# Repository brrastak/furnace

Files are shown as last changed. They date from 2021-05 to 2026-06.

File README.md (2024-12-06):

# Furnace for glass fusing

Glass fusing - joining of the pieces of glass. Glass isn't really melted, but is softer than in the normal condition. Planned furnace maximum temperature - 900 °C. Unfortunetely, the project was cancelled due to political reasons. I just want to close my gestalt and finish at least PCBs and firmware.

TODO: more detailed description.

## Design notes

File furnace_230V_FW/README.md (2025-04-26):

# Furnace 230V Board Firmware

## Description

[The board](../furnace_230V_HW/README.md) is equipped with an STM8S001J3 microcontroller. Its purpose is to measure the mains voltage connected to a load, the load current, and the temperature of the triac.  
The program is simple, but - in my opinion - quite elegant. It utilizes a [simple HAL](https://github.com/brrastak/stm8s-hal.git) that I created specifically for this project, implements a single-pole digital filter for the measured analog signals, and sends the data to a controller board.

## Build Workflow

Unfortunately, STM8 is not supported by LLVM and consequently not by Rust.  
But using Rust is just so much fun! So I use a fancy workflow to compile my Rust program:

1. Compile the Rust code to the `wasm32-unknown-unknown` target.
2. Translate the Wasm code into C code using the `wasm2c` tool from the awesome [WABT project](https://github.com/WebAssembly/wabt).
3. Clean up the generated C code using a Python script, since Wasm uses a specific memory model and a byte order incompatible with the STM8 architecture. (Note: there is still an unresolved issue with handling read-only static memory, such as lookup tables.)
4. Compile and flash the final C code to the device.

## Tools Installation

- Install `wabt` (for `wasm2c`):

```bash
sudo apt install wabt
```

- [Download](https://sourceforge.net/projects/sdcc/files/snapshot_builds/) and install SDCC:

```bash
sudo apt install bison flex texinfo libboost-all-dev
./configure
make
sudo make install
```

- [Clone](https://github.com/vdudouyt/stm8flash) and install `stm8flash`:

```bash
sudo apt install pkg-config libusb-1.0-0-dev
make
sudo make install
```

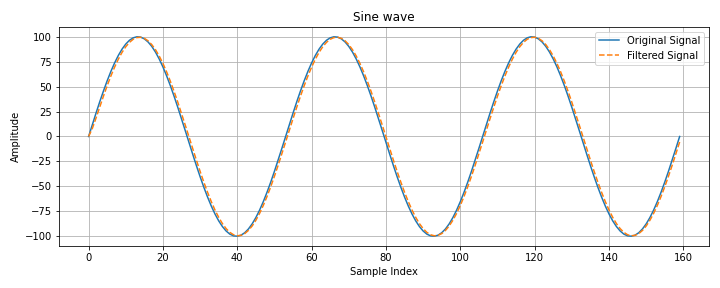
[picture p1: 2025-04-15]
simulations/digital_filter_simulation/plots/Sine wave.png

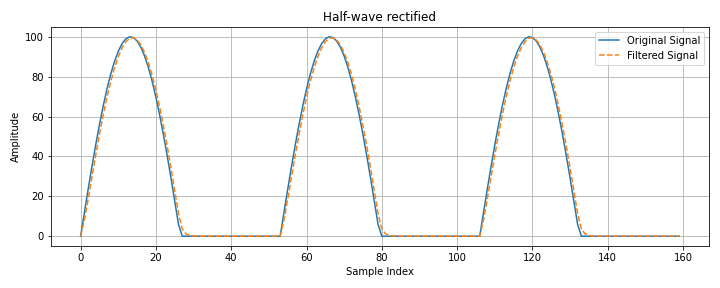
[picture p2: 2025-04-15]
simulations/digital_filter_simulation/plots/Half-wave rectified.png

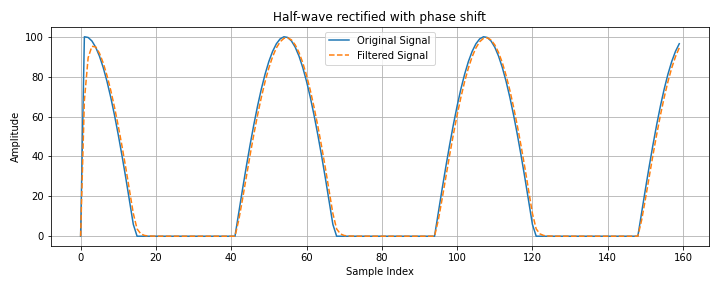
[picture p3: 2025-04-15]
simulations/digital_filter_simulation/plots/Half-wave rectified with phase shift.png

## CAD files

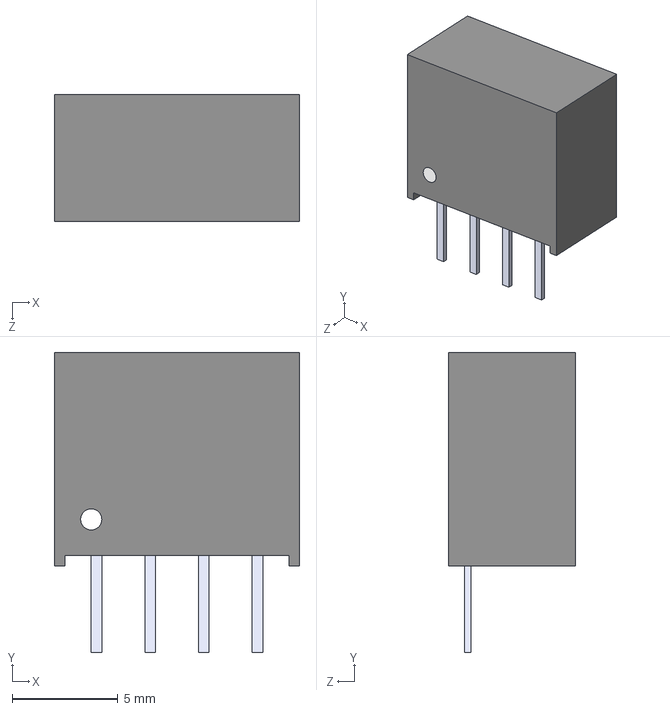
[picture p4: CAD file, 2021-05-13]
furnace_controller_HW/B0505S-1WR2.step
11.6 x 14.2 x 6.00 mm

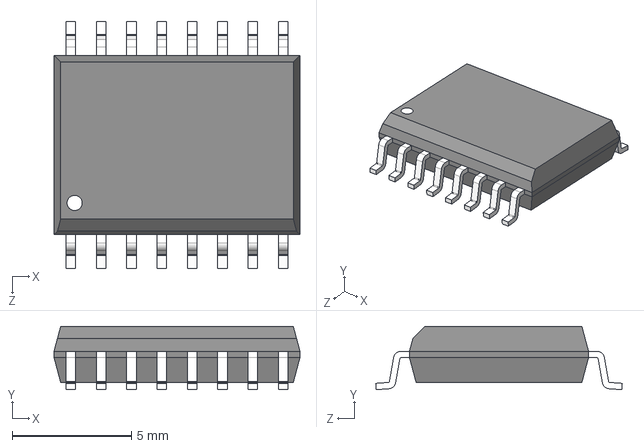
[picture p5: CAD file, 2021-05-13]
furnace_controller_HW/ADUM1301ARWZ-RL.step
10.3 x 2.65 x 10.3 mm

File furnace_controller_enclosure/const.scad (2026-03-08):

/*
    Module containing constants
*/

// OLED display recess
disp_width = 39;
disp_length = 62;
disp_x = 44;
disp_y = 22;

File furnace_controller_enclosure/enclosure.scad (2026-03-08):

//-----------------------------------------------------------------------
// Yet Another Parameterized Projectbox generator
//
//  This is a box for the furnace controller board
//
//  Version 3.3.7 (2025-04-17)
//
// This design is parameterized based on the size of a PCB.
//
// For many/complex cutoutGrills, you might need to adjust
//  the max number of elements in OpenSCAD:
//
//      Preferences->Advanced->Turn off rendering at 250000 elements
//                                                   ^^^^^^
//
//-----------------------------------------------------------------------

include <const.scad>
include <YAPPgenerator_v3.scad>


//---------------------------------------------------------
// This design is parameterized based on the size of a PCB.
//---------------------------------------------------------
// Note: length/lengte refers to X axis, 
//       width/breedte refers to Y axis,
//       height/hoogte refers to Z axis

/*
      padding-back|<------pcb length --->|<padding-front
                            RIGHT
        0    X-axis ---> 
        +----------------------------------------+   ---
        |                                        |    ^
        |                                        |   padding-right 
      Y |                                        |    v
      | |    -5,y +----------------------+       |   ---              
 B    a |         | 0,y              x,y |       |     ^              F
 A    x |         |                      |       |     |              R
 C    i |         |                      |       |     | pcb width    O
 K    s |         |                      |       |     |              N
        |         | 0,0              x,0 |       |     v              T
      ^ |    -5,0 +----------------------+       |   ---
      | |                                        |    padding-left
      0 +----------------------------------------+   ---
        0    X-as --->
                          LEFT
*/


//-- which part(s) do you want to print?
printBaseShell        = true;
printLidShell         = true;
printSwitchExtenders  = true;
printDisplayClips     = true;


myPcb = "./pcb/PCB.stl";

if (true)
{
    translate([paddingBack + wallThickness, paddingLeft + wallThickness, basePlaneThickness + standoffHeight]) 
    {
        rotate([0, 0, 90]) color("Blue") import(myPcb);
    }
}


// ********************************************************************
// The Following will be used as the first element in the pbc array

//Defined here so you can define the "Main" PCB using these if wanted
pcbLength           = 100; // front to back (X axis)
pcbWidth            = 88; // side to side (Y axis)
pcbThickness        = 1.6; 
standoffHeight      = 3.0; //-- How much the PCB needs to be raised from the base to leave room for solderings and whatnot
standoffDiameter    = 6.5;
standoffPinDiameter = 3.5;
standoffHoleSlack   = 0.2;

//===================================================================
// *** PCBs ***
// Printed Circuit Boards
//-------------------------------------------------------------------
//  Default origin =  yappCoordPCB : yappCoordBoxInside[0,0,0]
//
//  Parameters:
//   Required:
//    p(0) = name
//    p(1) = length
//    p(2) = width
//    p(3) = posx
//    p(4) = posy
//    p(5) = Thickness
//    p(6) = standoff_Height = Height to bottom of PCB from the inside of the base
//             negative measures from inside of the lid to the top of the PCB
//    p(7) = standoff_Diameter
//    p(8) = standoff_PinDiameter
//   Optional:
//    p(9) = standoff_HoleSlack (default to 0.4)

//The following can be used to get PCB values elsewhere in the script - not in pcb definition. 
//If "PCB Name" is omitted then "Main" is used
//  pcbLength           --> pcbLength("PCB Name")
//  pcbWidth            --> pcbWidth("PCB Name")
//  pcbThickness        --> pcbThickness("PCB Name") 
//  standoffHeight      --> standoffHeight("PCB Name") 
//  standoffDiameter    --> standoffDiameter("PCB Name") 
//  standoffPinDiameter --> standoffPinDiameter("PCB Name") 
//  standoffHoleSlack   --> standoffHoleSlack("PCB Name") 

pcb = 
[
  // Default Main PCB - DO NOT REMOVE the "Main" line.
  ["Main",              pcbLength,pcbWidth,    0,0,    pcbThickness,  standoffHeight, standoffDiameter, standoffPinDiameter, standoffHoleSlack]
];

//-------------------------------------------------------------------                            
//-- padding between pcb and inside wall
paddingFront        = 25;
paddingBack         = 5;
paddingRight        = 2;
paddingLeft         = 25;

//-- Edit these parameters for your own box dimensions
wallThickness       = 4;
basePlaneThickness  = 4;
lidPlaneThickness   = 4;

//-- Total height of box = lidPlaneThickness 
//                       + lidWallHeight 
//--                     + baseWallHeight 
//                       + basePlaneThickness
//-- space between pcb and lidPlane :=
//--      (bottonWallHeight+lidWallHeight) - (standoffHeight+pcbThickness)
baseWallHeight      = 14.5;
lidWallHeight       = 4.5;

//-- ridge where base and lid off box can overlap
//-- Make sure this isn't less than lidWallHeight
ridgeHeight         = 8;
ridgeSlack          = 0.2; // Gap between the inside of the lid and the outside of the base
//New in v3.3.7 
ridgeGap            = 0.1; // Gap between the bottom of the base ridge and the bottom of the lid when assembled.
roundRadius         = 2;

// Box Types are 0-4 with 0 as the default
// 0 = All edges rounded with radius (roundRadius) above
// 1 = All edges sqrtuare
// 2 = All edges chamfered by (roundRadius) above 
// 3 = Square top and bottom edges (the ones that touch the build plate) and rounded vertical edges
// 4 = Square top and bottom edges (the ones that touch the build plate) and chamfered vertical edges
// 5 = Chanfered top and bottom edges (the ones that touch the build plate) and rounded vertical edges
boxType             = 4; // Default type 0

// Set the layer height of your printer
printerLayerHeight  = 0.2;


//---------------------------
//--     C O N T R O L     --
//---------------------------
// -- Render --
renderQuality             = 8;          //-> from 1 to 32, Default = 8

// --Preview --
previewQuality            = 5;          //-> from 1 to 32, Default = 5
showSideBySide            = true;       //-> Default = true
onLidGap                  = 0;  // tip don't override to animate the lid opening
colorLid                  = "YellowGreen";   
alphaLid                  = 1;
colorBase                 = "BurlyWood";
alphaBase                 = 1;
hideLidWalls              = false;      //-> Remove the walls from the lid : only if preview and showSideBySide=true 
hideBaseWalls             = false;      //-> Remove the walls from the base : only if preview and showSideBySide=true  
showOrientation           = true;       //-> Show the Front/Back/Left/Right labels : only in preview
showPCB                   = false;      //-> Show the PCB in red : only in preview 
showSwitches              = false;      //-> Show the switches (for pushbuttons) : only in preview 
showButtonsDepressed      = false;      //-> Should the buttons in the Lid On view be in the pressed position
showOriginCoordBox        = false;      //-> Shows red bars representing the origin for yappCoordBox : only in preview 
showOriginCoordBoxInside  = false;      //-> Shows blue bars representing the origin for yappCoordBoxInside : only in preview 
showOriginCoordPCB        = false;      //-> Shows blue bars representing the origin for yappCoordBoxInside : only in preview 
showMarkersPCB            = false;      //-> Shows black bars corners of the PCB : only in preview 
showMarkersCenter         = false;      //-> Shows magenta bars along the centers of all faces  
inspectX                  = 0;          //-> 0=none (>0 from Back)
inspectY                  = 0;          //-> 0=none (>0 from Right)
inspectZ                  = 0;          //-> 0=none (>0 from Bottom)
inspectXfromBack          = true;       //-> View from the inspection cut foreward
inspectYfromLeft          = true;       //-> View from the inspection cut to the right
inspectZfromBottom        = true;       //-> View from the inspection cut up
//---------------------------
//--     C O N T R O L     --
//---------------------------

//-------------------------------------------------------------------
//-------------------------------------------------------------------
// Start of Debugging config (used if not overridden in template)
// ------------------------------------------------------------------
// ------------------------------------------------------------------
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

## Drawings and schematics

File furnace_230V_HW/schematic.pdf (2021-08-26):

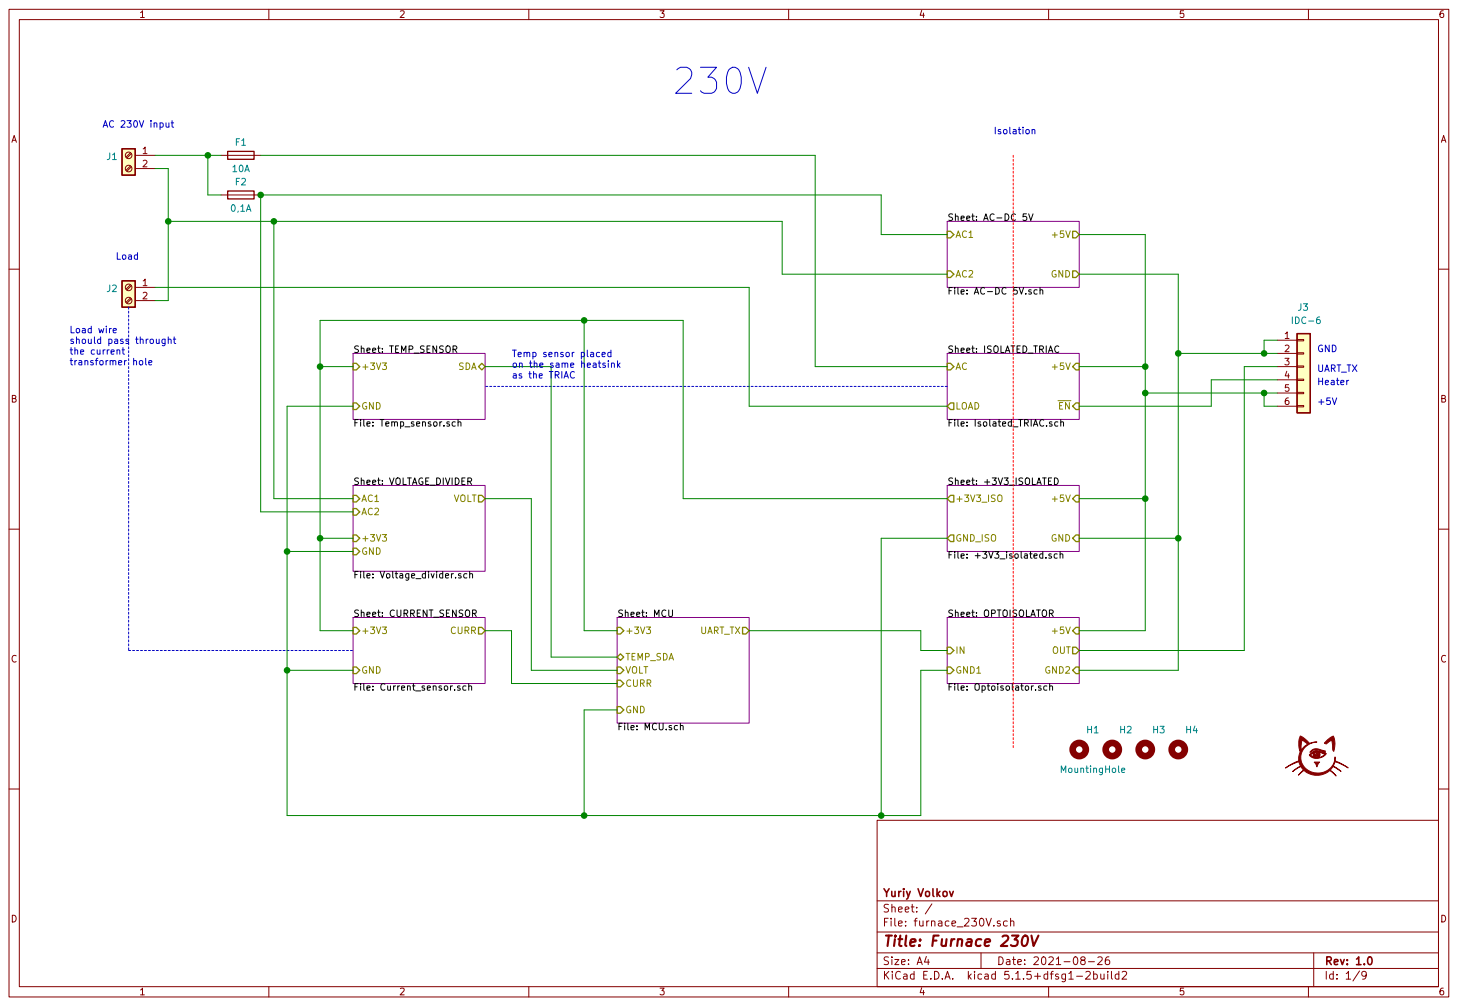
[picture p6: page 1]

Load wire should pass throught

File: furnace_230V.sch Sheet: / Yuriy Volkov

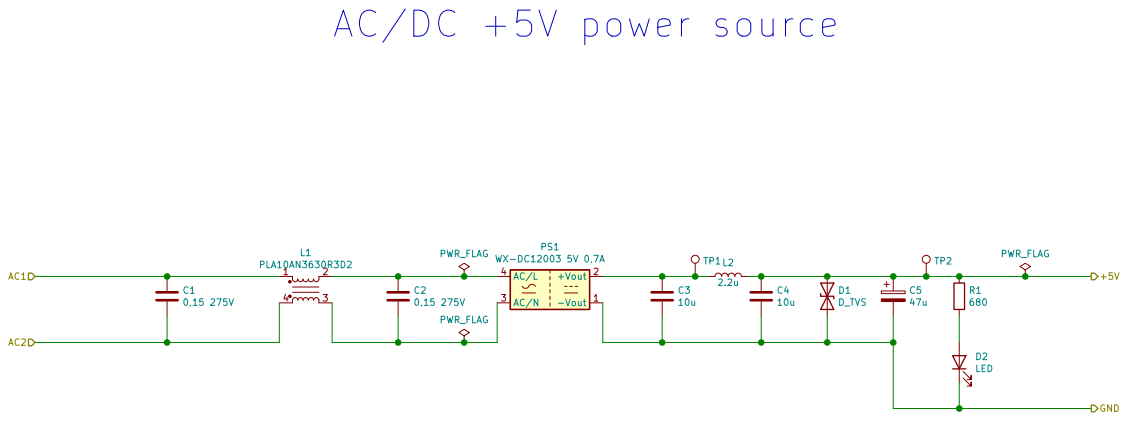
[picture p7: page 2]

File: AC-DC 5V.sch Sheet: /AC-DC 5V/ Yuriy Volkov

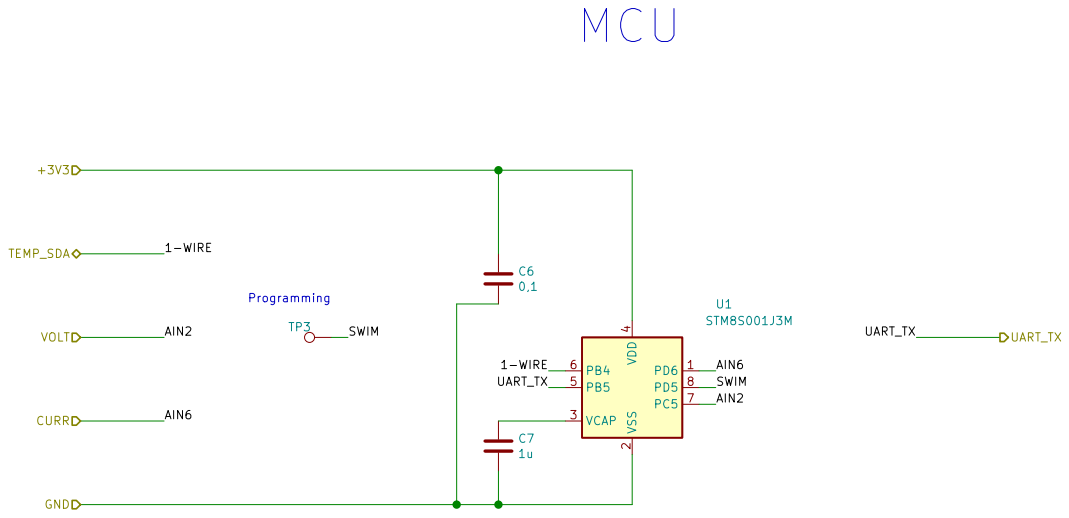
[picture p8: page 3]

File: MCU.sch Sheet: /MCU/ Yuriy Volkov C7

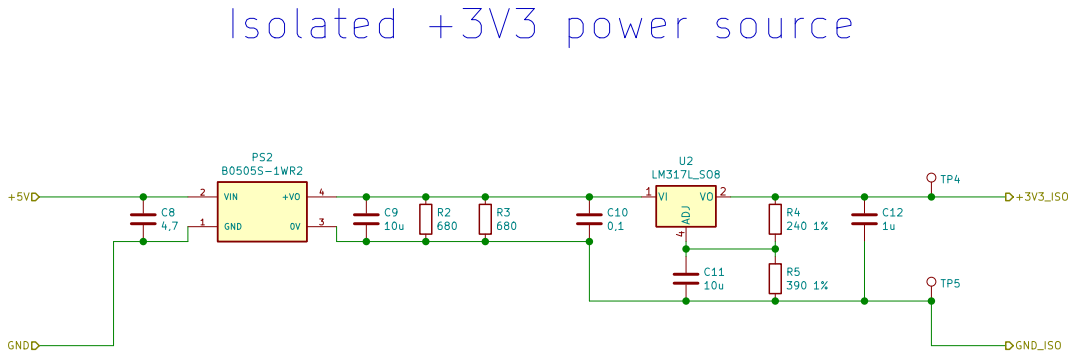
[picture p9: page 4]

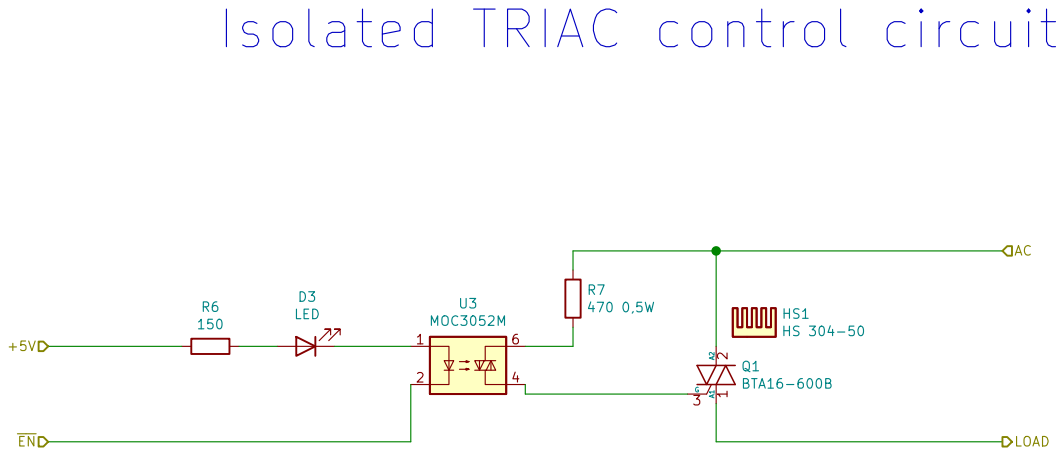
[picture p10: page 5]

AC Isolated TRIAC control circuit

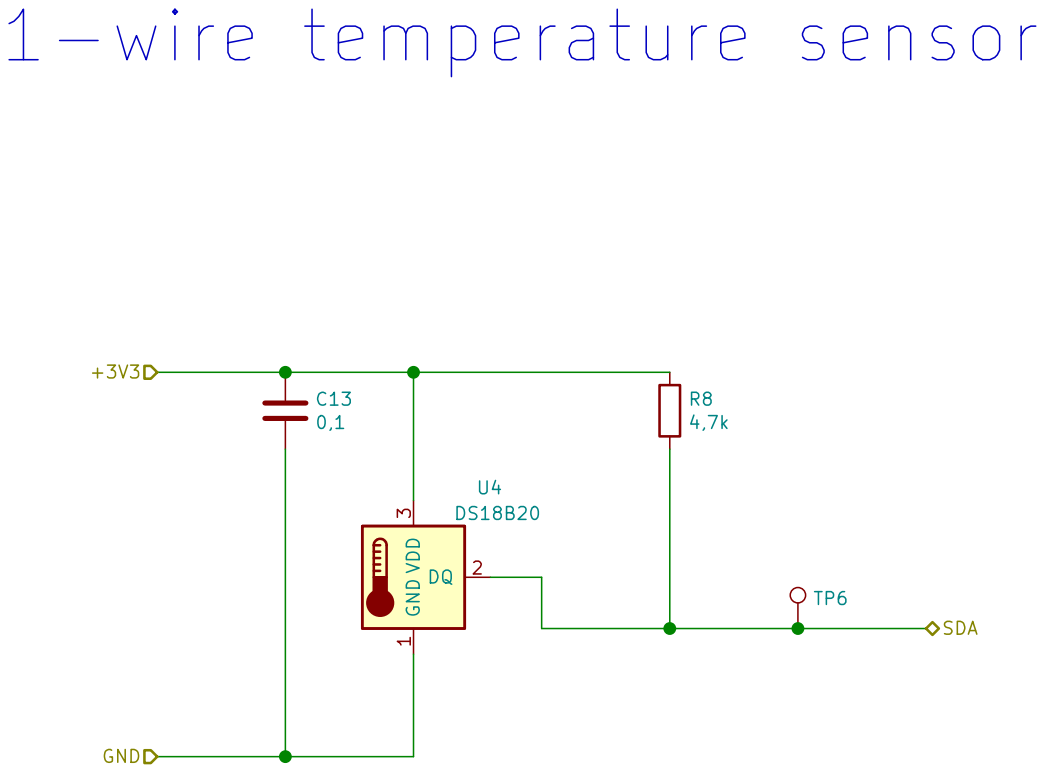
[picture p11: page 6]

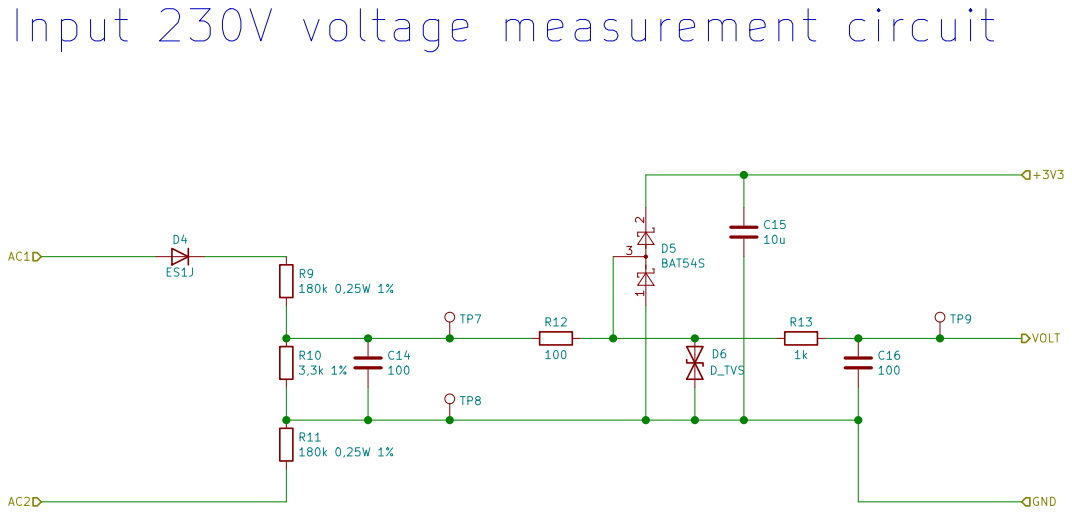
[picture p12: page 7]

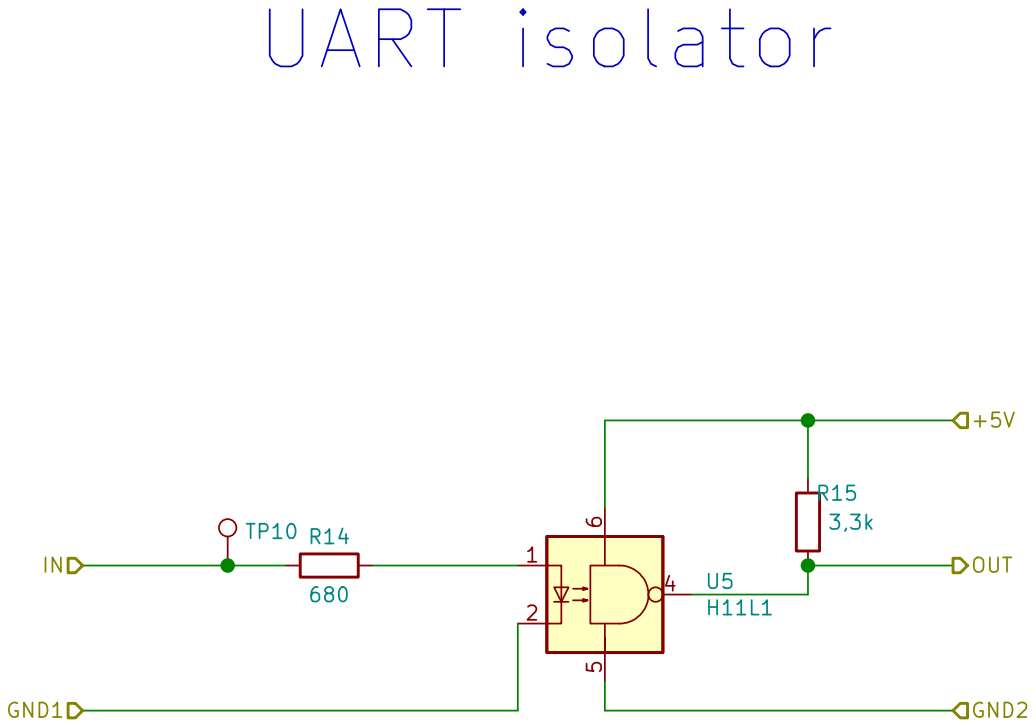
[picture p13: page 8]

File: Optoisolator.sch Sheet: /OPTOISOLATOR/ Yuriy Volkov R14

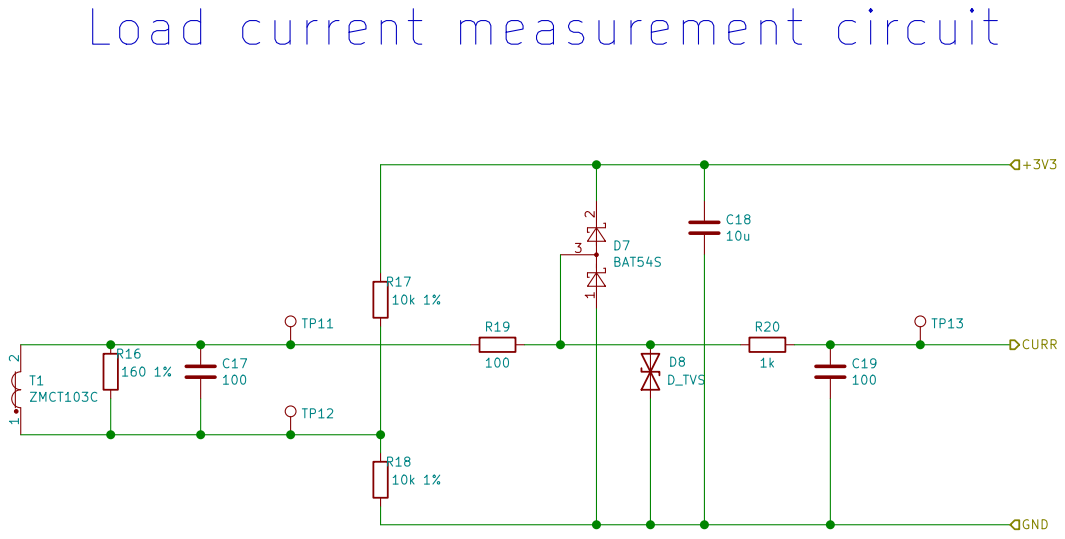
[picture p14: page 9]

+3V3 GND Load current measurement circuit

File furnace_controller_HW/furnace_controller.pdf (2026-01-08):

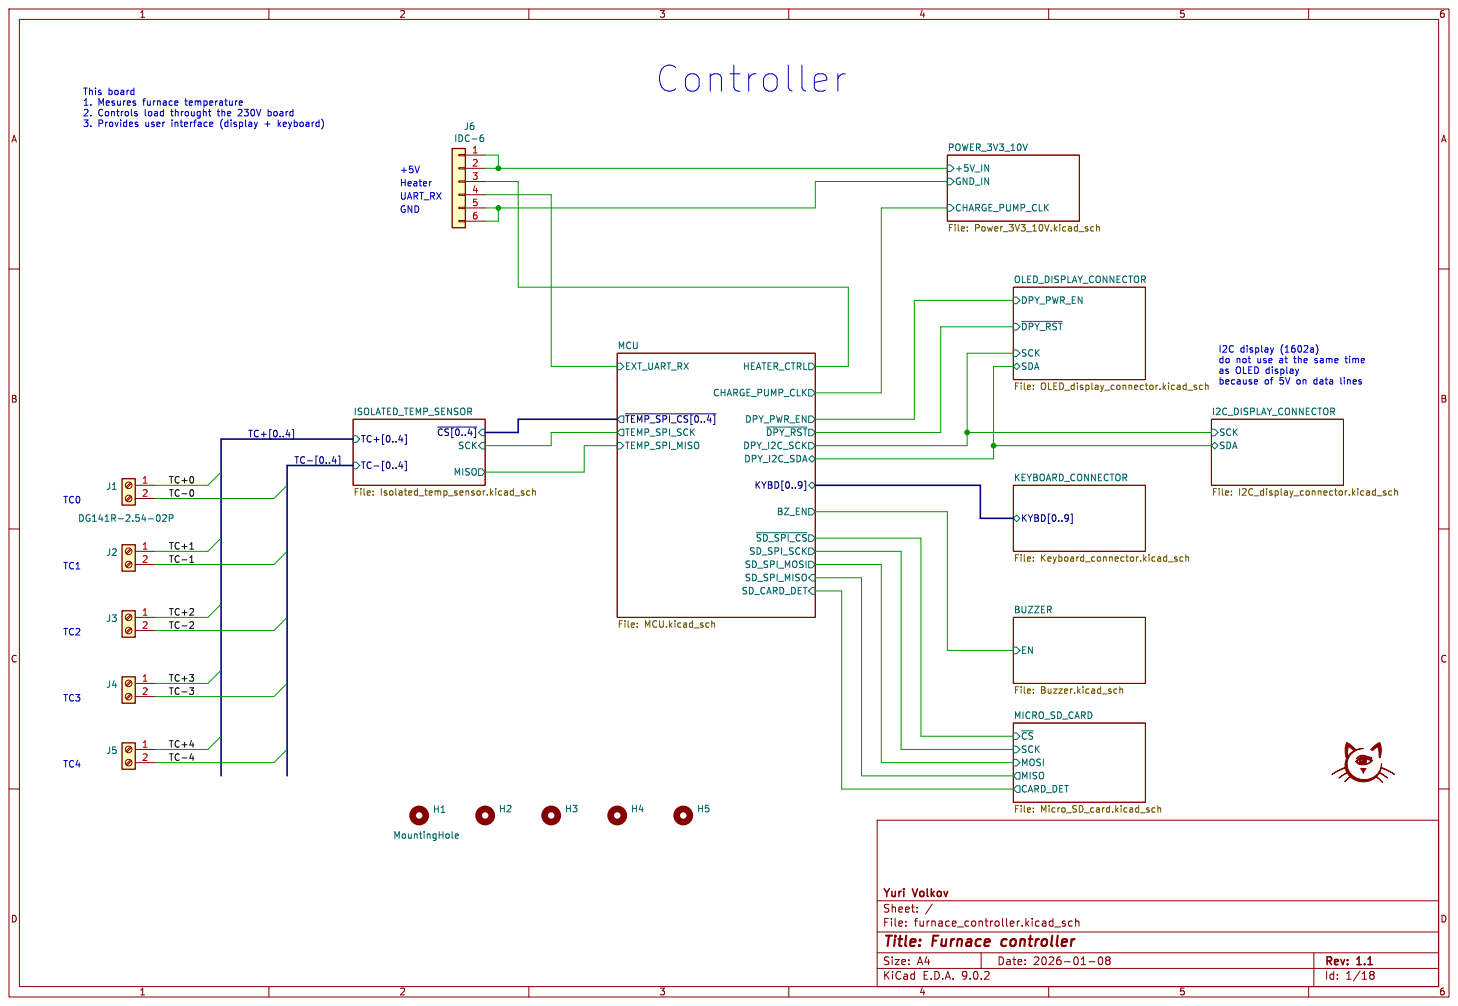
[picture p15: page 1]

as OLED display because of 5V on data lines UART_RX

I2C display (1602a) do not use at the same time

File: Buzzer.kicad_sch ~{CS} MOSI SCK MISO

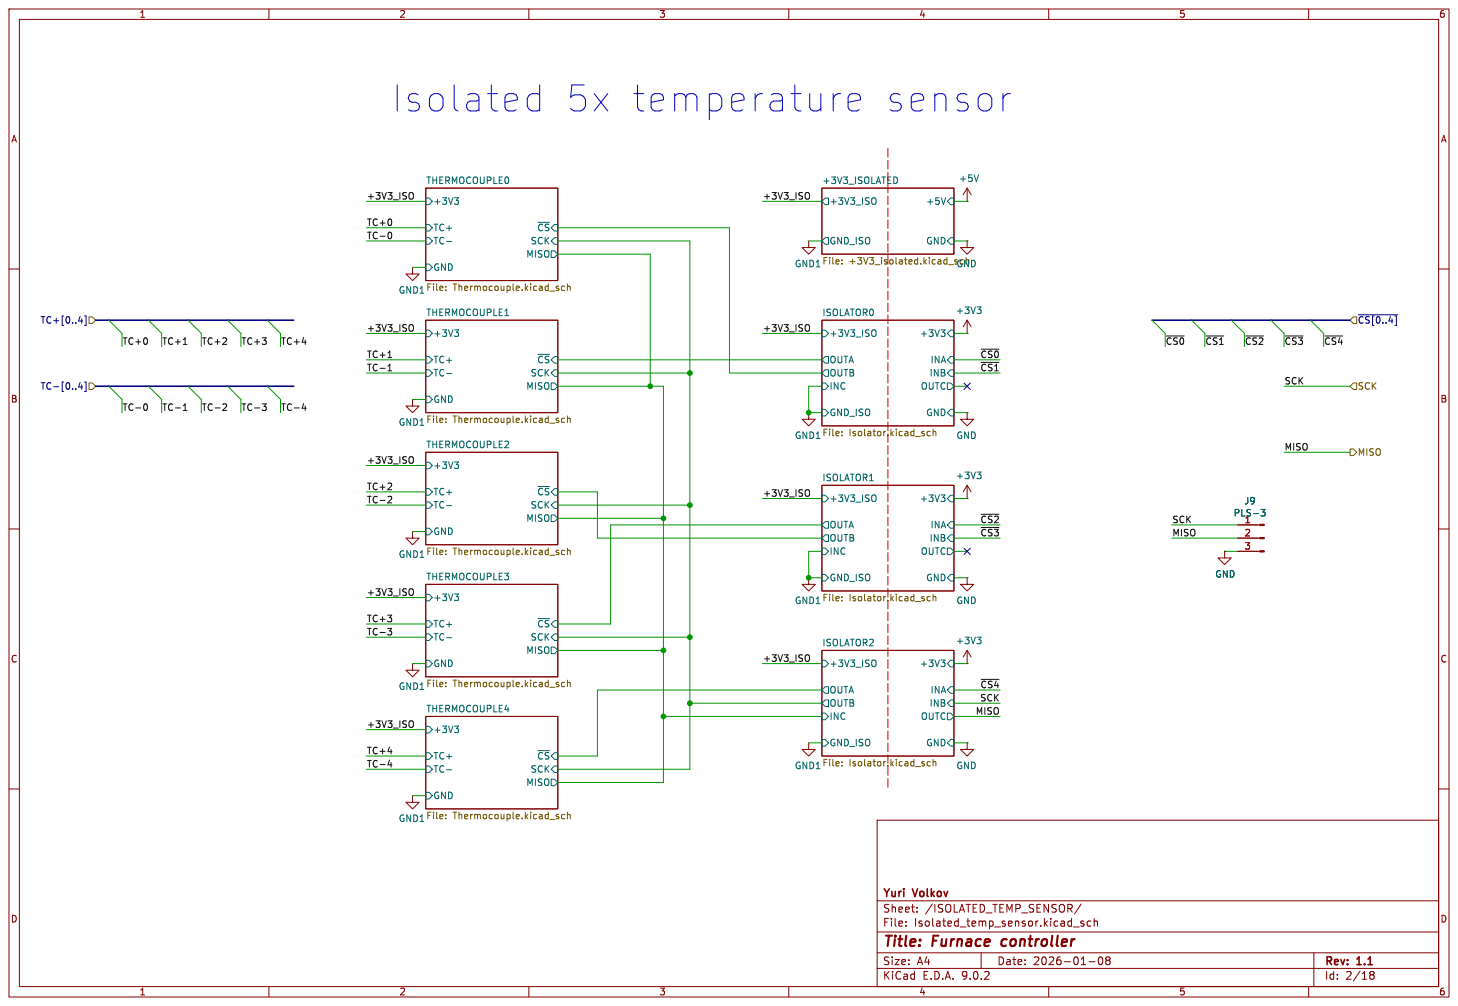
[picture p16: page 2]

Id: 2/18 Title: Furnace controller File: Isolated_temp_sensor.kicad_sch Sheet: /ISOLATED_TEMP_SENSOR/ Yuri Volkov

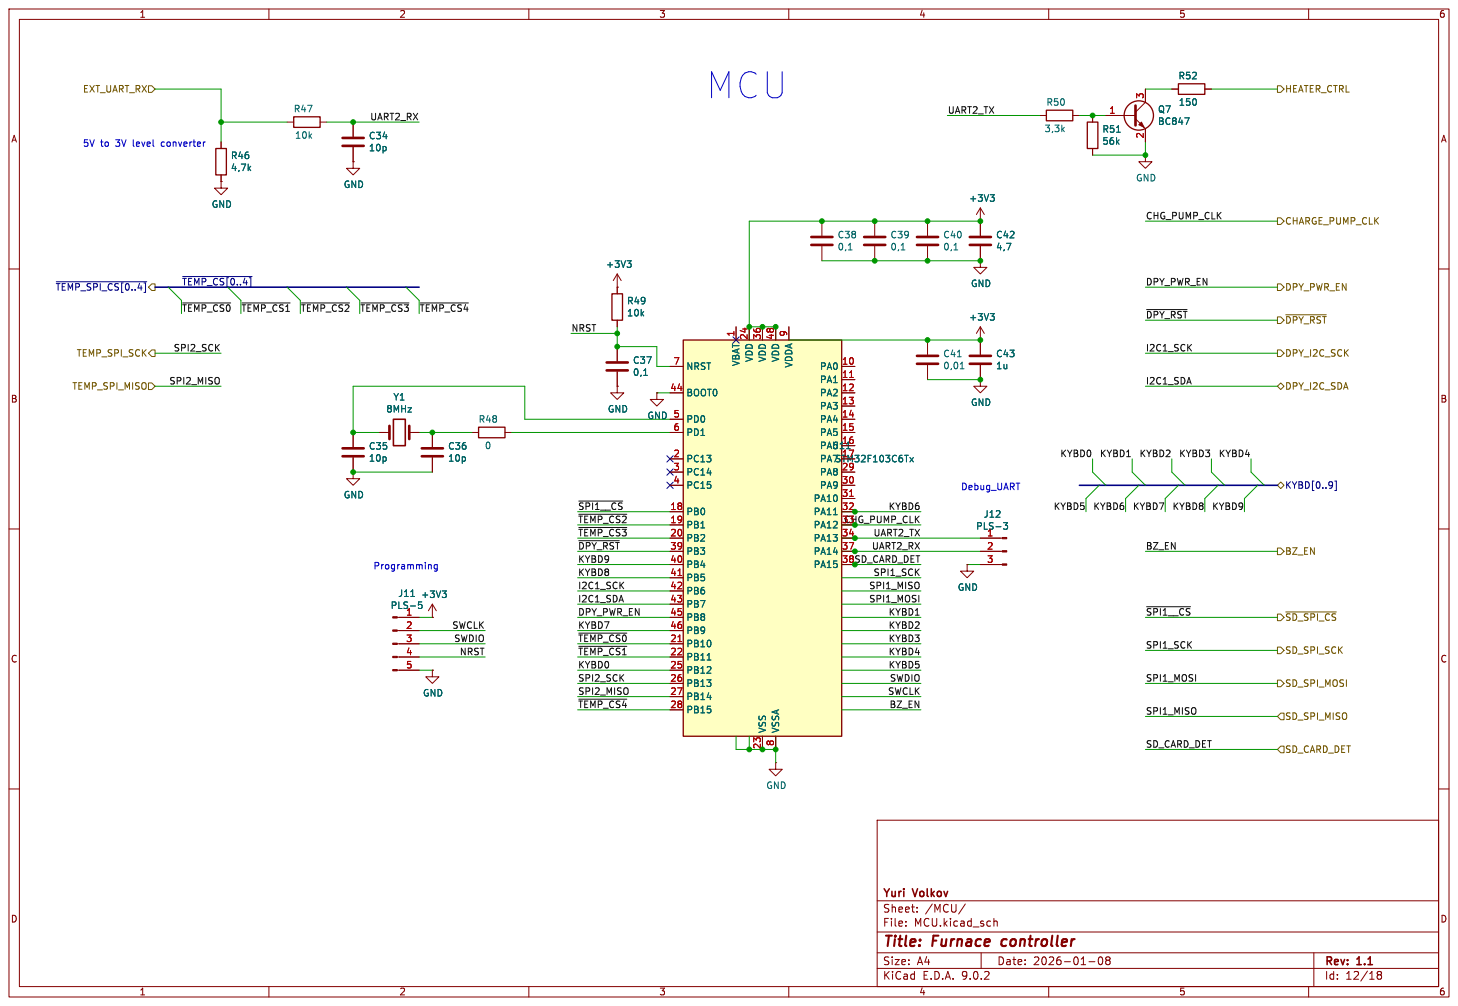
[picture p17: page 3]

1 VDD 24 VDD 36 VSS 23 VDD 48 VSSA

Id: 12/18 Title: Furnace controller File: MCU.kicad_sch Sheet: /MCU/ Yuri Volkov


Id: 13/18 Title: Furnace controller File: Power_3V3_10V.kicad_sch Sheet: /POWER_3V3_10V/ Yuri Volkov



Id: 15/18 Title: Furnace controller File: Keyboard_connector.kicad_sch Sheet: /KEYBOARD_CONNECTOR/ Yuri Volkov


Id: 16/18 Title: Furnace controller File: Buzzer.kicad_sch Sheet: /BUZZER/ Yuri Volkov


Id: 17/18 Title: Furnace controller File: Micro_SD_card.kicad_sch Sheet: /MICRO_SD_CARD/ Yuri Volkov R54


Id: 18/18 Title: Furnace controller File: I2C_display_connector.kicad_sch Sheet: /I2C_DISPLAY_CONNECTOR/ Yuri Volkov


1 SCK 5 SO 7 ~{CS}6 U2 MAX31855EASA MISO

Id: 3/18 Title: Furnace controller File: Thermocouple.kicad_sch Sheet: /ISOLATED_TEMP_SENSOR/THERMOCOUPLE0/ Yuri Volkov


1 SCK 5 SO 7 ~{CS}6 U5 MAX31855EASA MISO

Id: 4/18 Title: Furnace controller File: Thermocouple.kicad_sch Sheet: /ISOLATED_TEMP_SENSOR/THERMOCOUPLE1/ Yuri Volkov


1 SCK 5 SO 7 ~{CS}6 U6 MAX31855EASA MISO

Id: 5/18 Title: Furnace controller File: Thermocouple.kicad_sch Sheet: /ISOLATED_TEMP_SENSOR/THERMOCOUPLE2/ Yuri Volkov


1 SCK 5 SO 7 ~{CS}6 U7 MAX31855EASA MISO

Id: 6/18 Title: Furnace controller File: Thermocouple.kicad_sch Sheet: /ISOLATED_TEMP_SENSOR/THERMOCOUPLE3/ Yuri Volkov


1 SCK 5 SO 7 ~{CS}6 U8 MAX31855EASA MISO

Id: 7/18 Title: Furnace controller File: Thermocouple.kicad_sch Sheet: /ISOLATED_TEMP_SENSOR/THERMOCOUPLE4/ Yuri Volkov


Id: 8/18 Title: Furnace controller File: +3V3_isolated.kicad_sch Sheet: /ISOLATED_TEMP_SENSOR/+3V3_ISOLATED/ Yuri Volkov C20


Id: 9/18 Title: Furnace controller File: Isolator.kicad_sch Sheet: /ISOLATED_TEMP_SENSOR/ISOLATOR0/ Yuri Volkov


Id: 10/18 Title: Furnace controller File: Isolator.kicad_sch Sheet: /ISOLATED_TEMP_SENSOR/ISOLATOR1/ Yuri Volkov


Id: 11/18 Title: Furnace controller File: Isolator.kicad_sch Sheet: /ISOLATED_TEMP_SENSOR/ISOLATOR2/ Yuri Volkov

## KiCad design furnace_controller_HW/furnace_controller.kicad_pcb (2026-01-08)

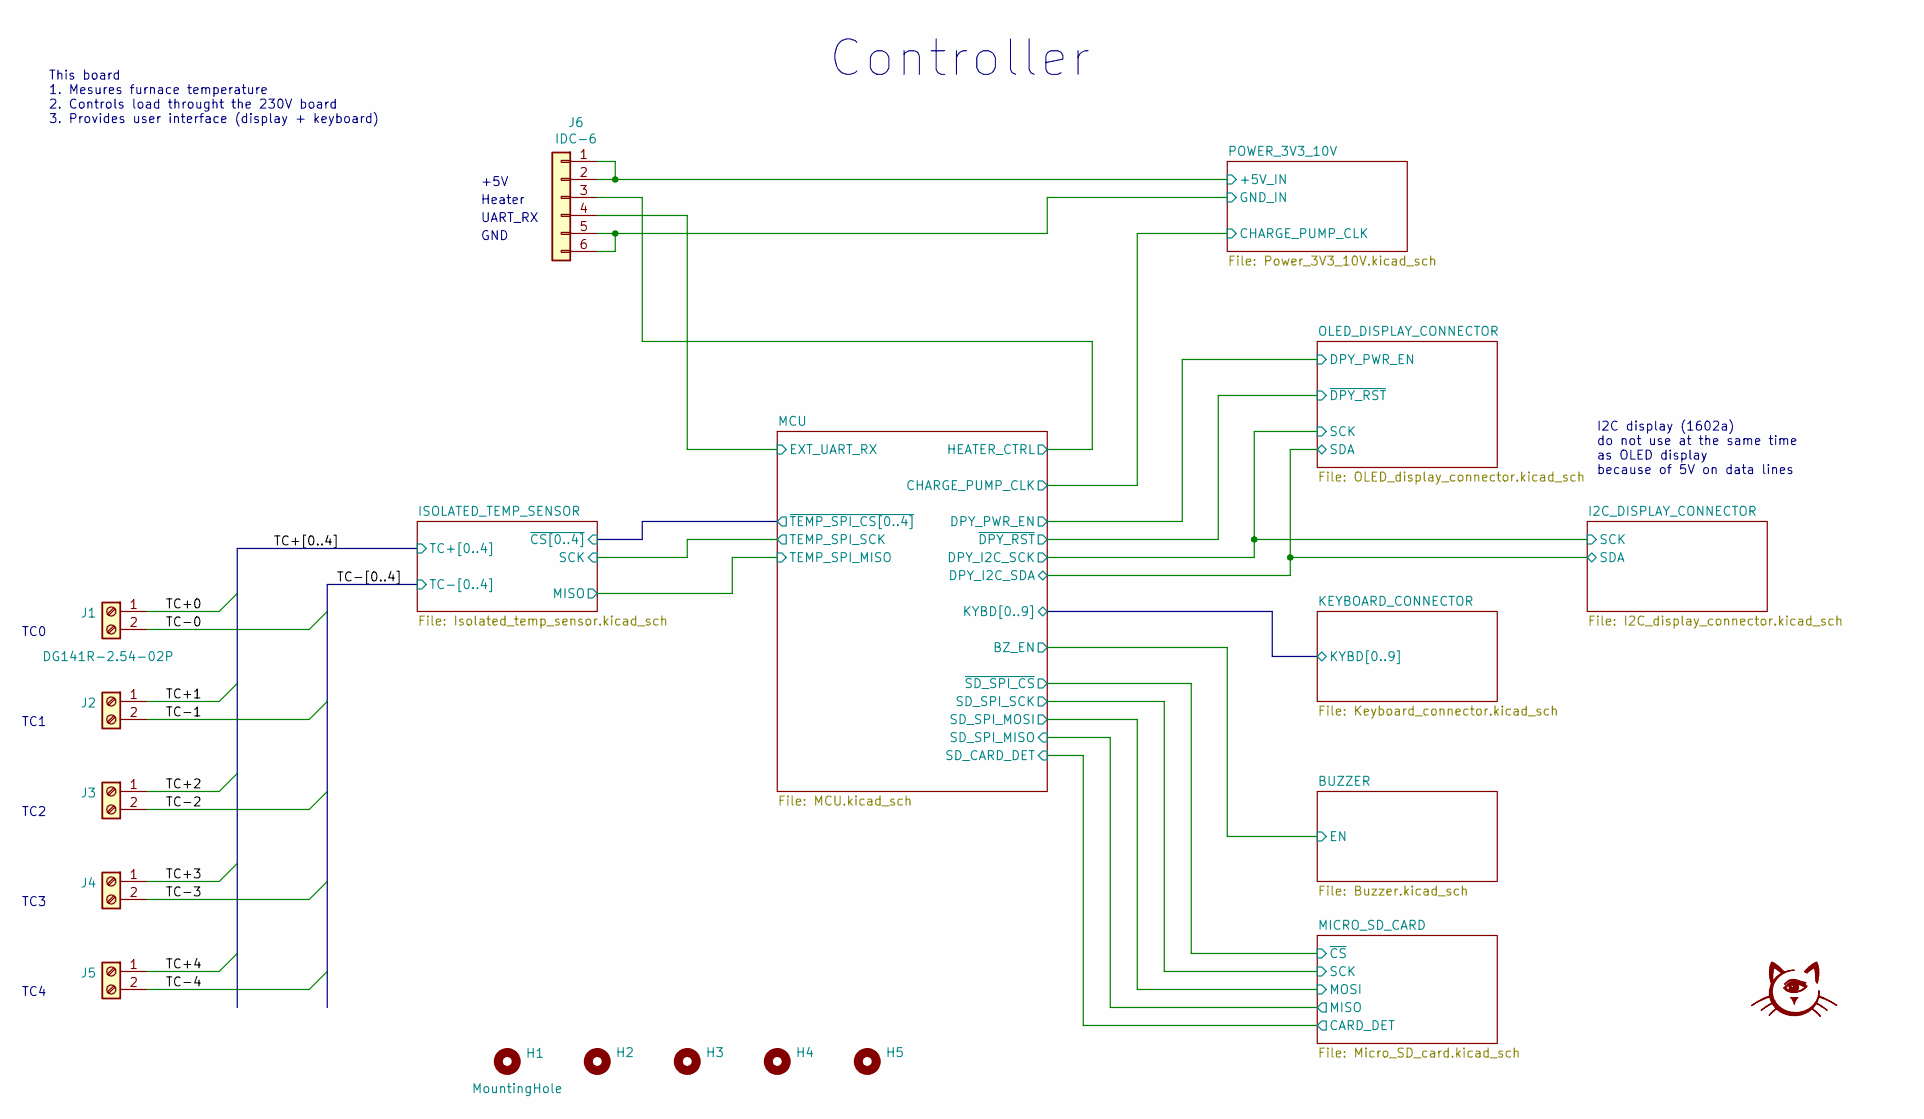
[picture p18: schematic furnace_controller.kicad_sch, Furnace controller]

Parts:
G1: LOGO; stamp
H1, H2, H3, H4, H5: MountingHole; hole_D3.5mm
J1, J2, J3, J4, J5: DG141R-2.54-02P
J6: IDC-6; IDC-Header_2x03_P2.54mm_Vertical

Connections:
/MCU/EXT_UART_RX: J6.4; also elsewhere on the board
/MCU/HEATER_CTRL: J6.3; also elsewhere on the board
/POWER_3V3_10V/+5V_IN: J6.1, J6.2; also elsewhere on the board
/TC+0: J1.1; also elsewhere on the board
/TC+1: J2.1; also elsewhere on the board
/TC+2: J3.1; also elsewhere on the board
/TC+3: J4.1; also elsewhere on the board
/TC+4: J5.1; also elsewhere on the board
/TC-0: J1.2; also elsewhere on the board
/TC-1: J2.2; also elsewhere on the board
/TC-2: J3.2; also elsewhere on the board
/TC-3: J4.2; also elsewhere on the board
/TC-4: J5.2; also elsewhere on the board
GND: J6.5, J6.6; also elsewhere on the board

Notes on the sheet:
Controller
TC0
UART_RX
GND
+5V
I2C display (1602a) do not use at the same time as OLED display because of 5V on data lines
TC2
TC1
TC4
TC3
This board 1. Mesures furnace temperature 2. Controls load throught the 230V board 3. Provides user interface (display + keyboard)
Heater

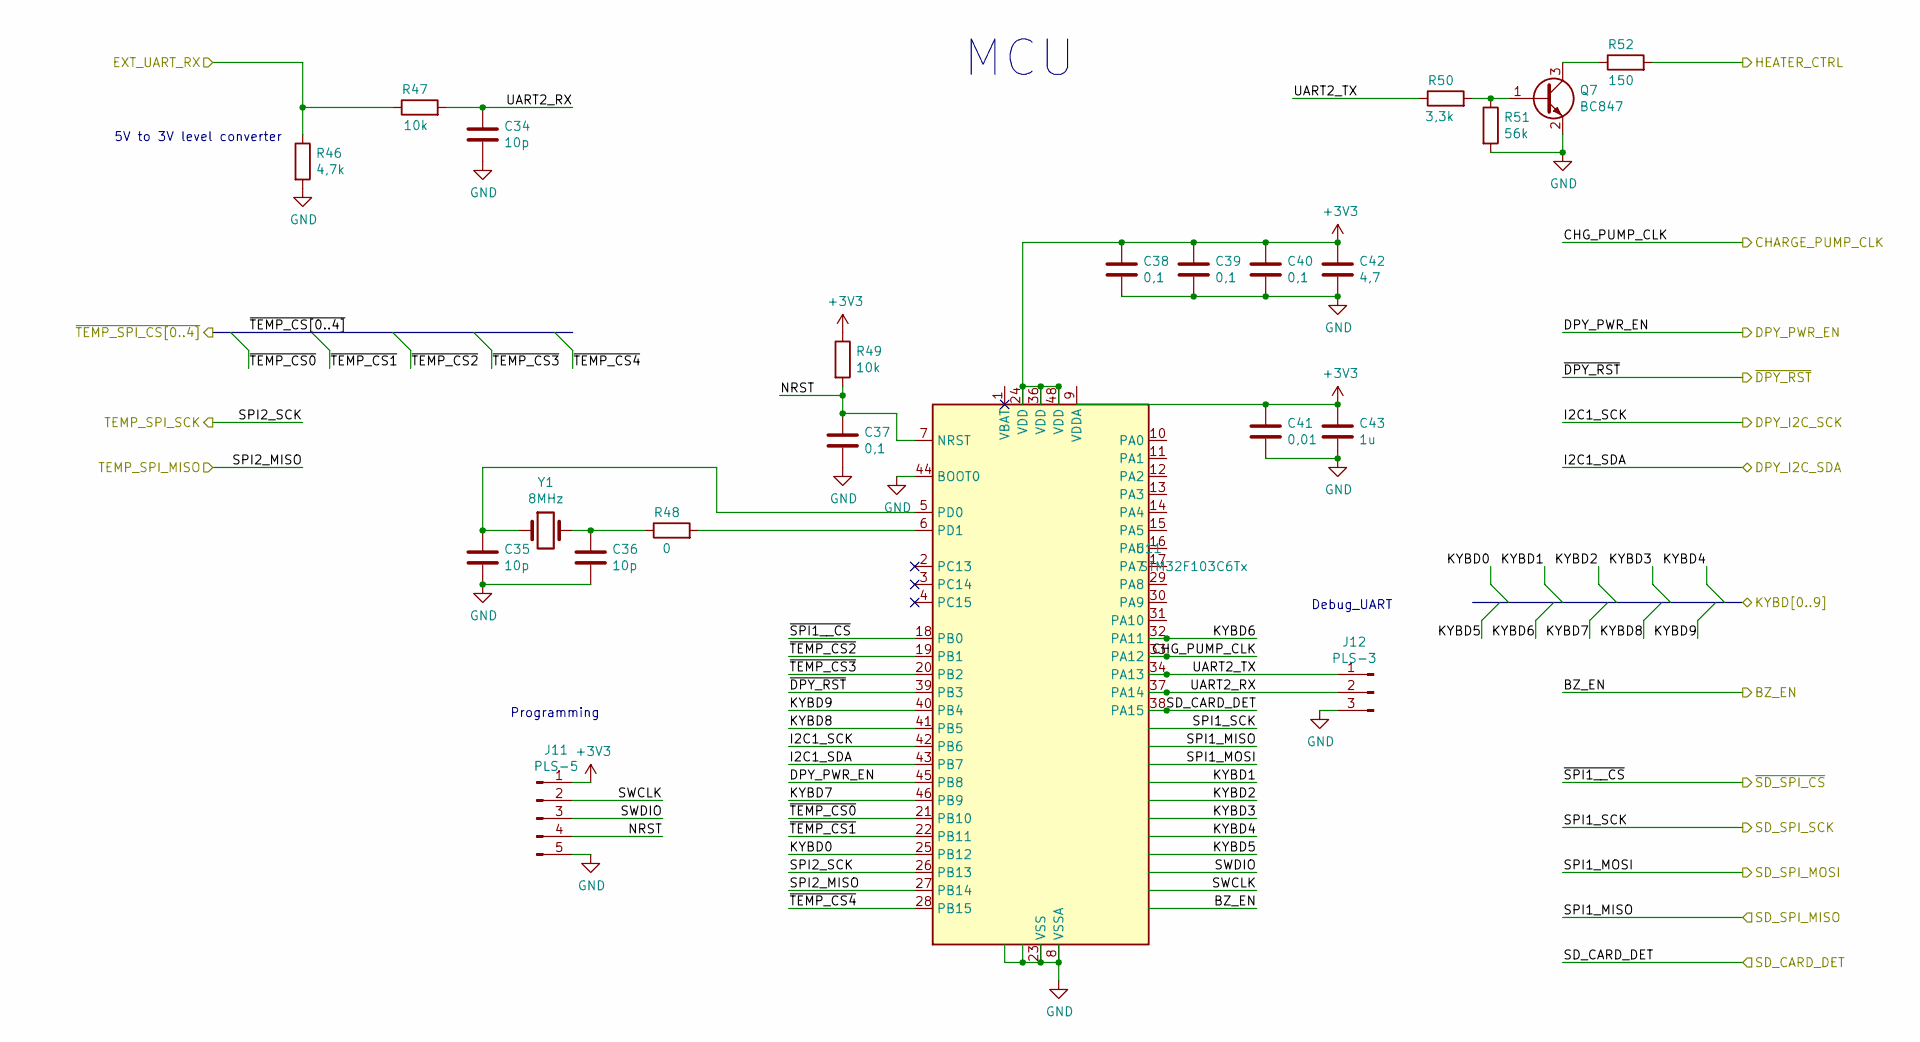
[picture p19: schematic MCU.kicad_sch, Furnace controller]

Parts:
C34, C35, C36: 10p; C_0603_1608Metric_Pad1.08x0.95mm_HandSolder
C37, C38, C39, C40: 0,1; C_0603_1608Metric_Pad1.08x0.95mm_HandSolder
C41: 0,01; C_0603_1608Metric_Pad1.08x0.95mm_HandSolder
C42: 4,7; C_1206_3216Metric_Pad1.33x1.80mm_HandSolder
C43: 1u; C_0603_1608Metric_Pad1.08x0.95mm_HandSolder
J11: PLS-5; PinHeader_1x05_P2.54mm_Vertical
J12: PLS-3; PinHeader_1x03_P2.54mm_Vertical
Q7: BC847; SOT-23
R46: 4,7k; R_0603_1608Metric_Pad0.98x0.95mm_HandSolder
R47, R49: 10k; R_0603_1608Metric_Pad0.98x0.95mm_HandSolder
R48: 0; R_0603_1608Metric_Pad0.98x0.95mm_HandSolder
R50: 3,3k; R_0603_1608Metric_Pad0.98x0.95mm_HandSolder
R51: 56k; R_0603_1608Metric_Pad0.98x0.95mm_HandSolder
R52: 150; R_0603_1608Metric_Pad0.98x0.95mm_HandSolder
U11: STM32F103C6Tx; LQFP-48_7x7mm_P0.5mm
Y1: 8MHz; Crystal_SMD_HC49-SD

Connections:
+3V3: C38.1, C39.1, C40.1, C41.1, C42.1, C43.1, J11.1, R49.1, U11.9 (VDDA), U11.24 (VDD), U11.36 (VDD), U11.48 (VDD); also elsewhere on the board
/ISOLATED_TEMP_SENSOR/MISO: U11.27 (PB14); also elsewhere on the board
/ISOLATED_TEMP_SENSOR/SCK: U11.26 (PB13); also elsewhere on the board
/ISOLATED_TEMP_SENSOR/~CS0: U11.21 (PB10); also elsewhere on the board
/ISOLATED_TEMP_SENSOR/~CS1: U11.22 (PB11); also elsewhere on the board
/ISOLATED_TEMP_SENSOR/~CS2: U11.19 (PB1); also elsewhere on the board
/ISOLATED_TEMP_SENSOR/~CS3: U11.20 (PB2); also elsewhere on the board
/ISOLATED_TEMP_SENSOR/~CS4: U11.28 (PB15); also elsewhere on the board
/KEYBOARD_CONNECTOR/KYBD0: U11.25 (PB12); also elsewhere on the board
/KEYBOARD_CONNECTOR/KYBD1: U11.29 (PA8); also elsewhere on the board
/KEYBOARD_CONNECTOR/KYBD2: U11.30 (PA9); also elsewhere on the board
/KEYBOARD_CONNECTOR/KYBD3: U11.31 (PA10); also elsewhere on the board
/KEYBOARD_CONNECTOR/KYBD4: U11.32 (PA11); also elsewhere on the board
/KEYBOARD_CONNECTOR/KYBD5: U11.33 (PA12); also elsewhere on the board
/KEYBOARD_CONNECTOR/KYBD6: U11.10 (PA0); also elsewhere on the board
/KEYBOARD_CONNECTOR/KYBD7: U11.46 (PB9); also elsewhere on the board
/KEYBOARD_CONNECTOR/KYBD8: U11.41 (PB5); also elsewhere on the board
/KEYBOARD_CONNECTOR/KYBD9: U11.40 (PB4); also elsewhere on the board
/MCU/BZ_EN: U11.38 (PA15); also elsewhere on the board
/MCU/CHARGE_PUMP_CLK: U11.11 (PA1); also elsewhere on the board
/MCU/DPY_I2C_SCK: U11.42 (PB6); also elsewhere on the board
/MCU/DPY_I2C_SDA: U11.43 (PB7); also elsewhere on the board
/MCU/DPY_PWR_EN: U11.45 (PB8); also elsewhere on the board
/MCU/EXT_UART_RX: R46.1, R47.1; also elsewhere on the board
/MCU/HEATER_CTRL: R52.2; also elsewhere on the board
/MCU/NRST: C37.1, J11.4, R49.2, U11.7 (NRST)
/MCU/~DPY_RST: U11.39 (PB3); also elsewhere on the board
/MICRO_SD_CARD/CARD_DET: U11.14 (PA4); also elsewhere on the board
/MICRO_SD_CARD/MISO: U11.16 (PA6); also elsewhere on the board
/MICRO_SD_CARD/MOSI: U11.17 (PA7); also elsewhere on the board
/MICRO_SD_CARD/SCK: U11.15 (PA5); also elsewhere on the board
/MICRO_SD_CARD/~CS: U11.18 (PB0); also elsewhere on the board
GND: C34.2, C35.2, C36.2, C37.2, C38.2, C39.2, C40.2, C41.2, C42.2, C43.2, J11.5, J12.3, Q7.2 (E), R46.2, R51.2, U11.8 (VSSA), U11.23 (VSS), U11.35 (VSS), U11.44 (BOOT0), U11.47 (VSS); also elsewhere on the board
unnamed: C35.1, U11.5 (PD0), Y1.1
unnamed: C36.1, R48.1, Y1.2
unnamed: Q7.1 (B), R50.2, R51.1
unnamed: Q7.3 (C), R52.1
unnamed: R48.2, U11.6 (PD1)

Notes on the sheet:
Debug_UART
Programming
MCU
5V to 3V level converter

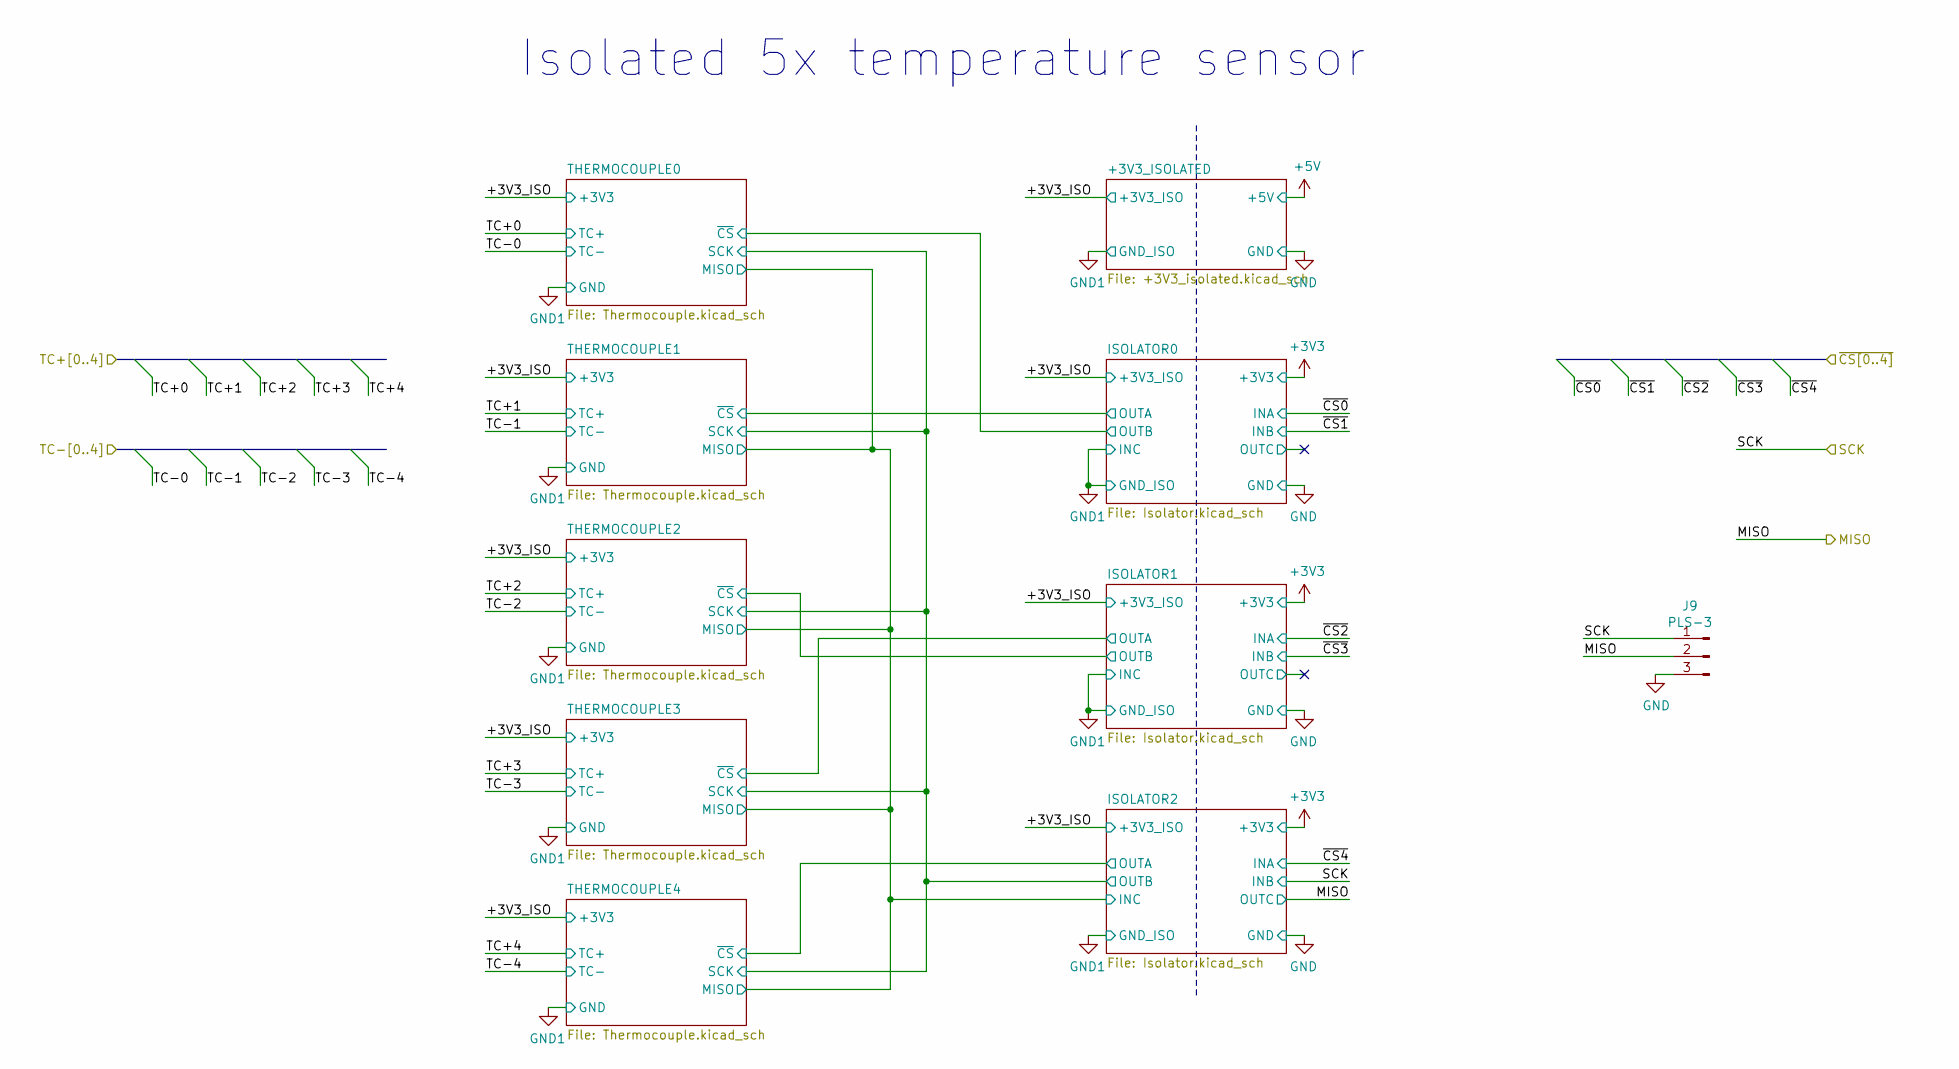
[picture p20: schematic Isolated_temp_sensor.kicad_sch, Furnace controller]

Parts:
J9: PLS-3; PinHeader_1x03_P2.54mm_Vertical

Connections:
/ISOLATED_TEMP_SENSOR/MISO: J9.2; also elsewhere on the board
/ISOLATED_TEMP_SENSOR/SCK: J9.1; also elsewhere on the board
GND: J9.3; also elsewhere on the board

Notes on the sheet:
Isolated 5x temperature sensor

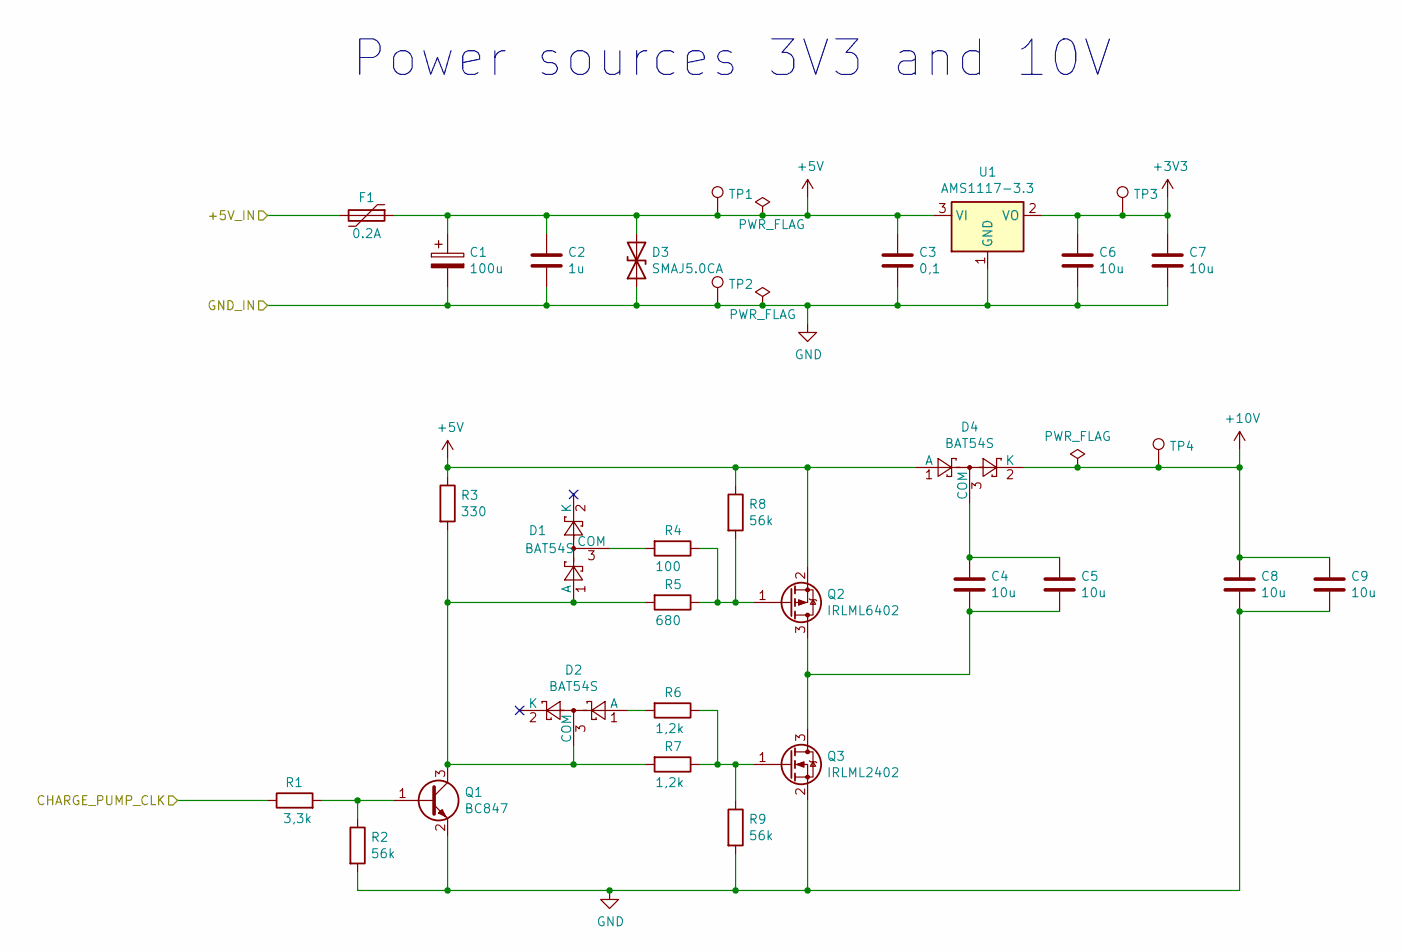
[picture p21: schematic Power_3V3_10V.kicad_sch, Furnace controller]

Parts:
C1: 100u; CP_Radial_D5.0mm_P2.00mm
C2: 1u; C_0603_1608Metric_Pad1.08x0.95mm_HandSolder
C3: 0,1; C_0603_1608Metric_Pad1.08x0.95mm_HandSolder
C4, C5, C6, C7, C8, C9: 10u; C_1206_3216Metric_Pad1.33x1.80mm_HandSolder
D1, D2, D4: BAT54S; SOT-23
D3: SMAJ5.0CA; D_SMB_Handsoldering
F1: 0.2A; Fuse_1206_3216Metric_Pad1.42x1.75mm_HandSolder
Q1: BC847; SOT-23
Q2: IRLML6402; SOT-23
Q3: IRLML2402; SOT-23
R1: 3,3k; R_0603_1608Metric_Pad0.98x0.95mm_HandSolder
R2, R8, R9: 56k; R_0603_1608Metric_Pad0.98x0.95mm_HandSolder
R3: 330; R_0603_1608Metric_Pad0.98x0.95mm_HandSolder
R4: 100; R_0603_1608Metric_Pad0.98x0.95mm_HandSolder
R5: 680; R_0603_1608Metric_Pad0.98x0.95mm_HandSolder
R6, R7: 1,2k; R_0603_1608Metric_Pad0.98x0.95mm_HandSolder
TP1, TP2, TP3, TP4: TestPoint; TP
U1: AMS1117-3.3; SOT-223-3_TabPin2

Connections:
+3V3: C6.1, C7.1, TP3.1, U1.2 (VO); also elsewhere on the board
+5V: C1.1, C2.1, C3.1, D3.2 (A2), D4.1 (A), F1.1, Q2.2 (S), R3.1, R8.1, TP1.1, U1.3 (VI); also elsewhere on the board
+10V: C8.1, C9.1, D4.2 (K), TP4.1; also elsewhere on the board
/MCU/CHARGE_PUMP_CLK: R1.1; also elsewhere on the board
/POWER_3V3_10V/+5V_IN: F1.2; also elsewhere on the board
GND: C1.2, C2.2, C3.2, C6.2, C7.2, C8.2, C9.2, D3.1 (A1), Q1.2 (E), Q3.2 (S), R2.2, R9.2, TP2.1, U1.1 (GND); also elsewhere on the board
unnamed: C4.1, C5.1, D4.3 (COM)
unnamed: C4.2, C5.2, Q2.3 (D), Q3.3 (D)
unnamed: D1.1 (A), D2.3 (COM), Q1.3 (C), R3.2, R5.2, R7.2
unnamed: D1.3 (COM), R4.2
unnamed: D2.1 (A), R6.2
unnamed: Q1.1 (B), R1.2, R2.1
unnamed: Q2.1 (G), R4.1, R5.1, R8.2
unnamed: Q3.1 (G), R6.1, R7.1, R9.1

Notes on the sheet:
Power sources 3V3 and 10V

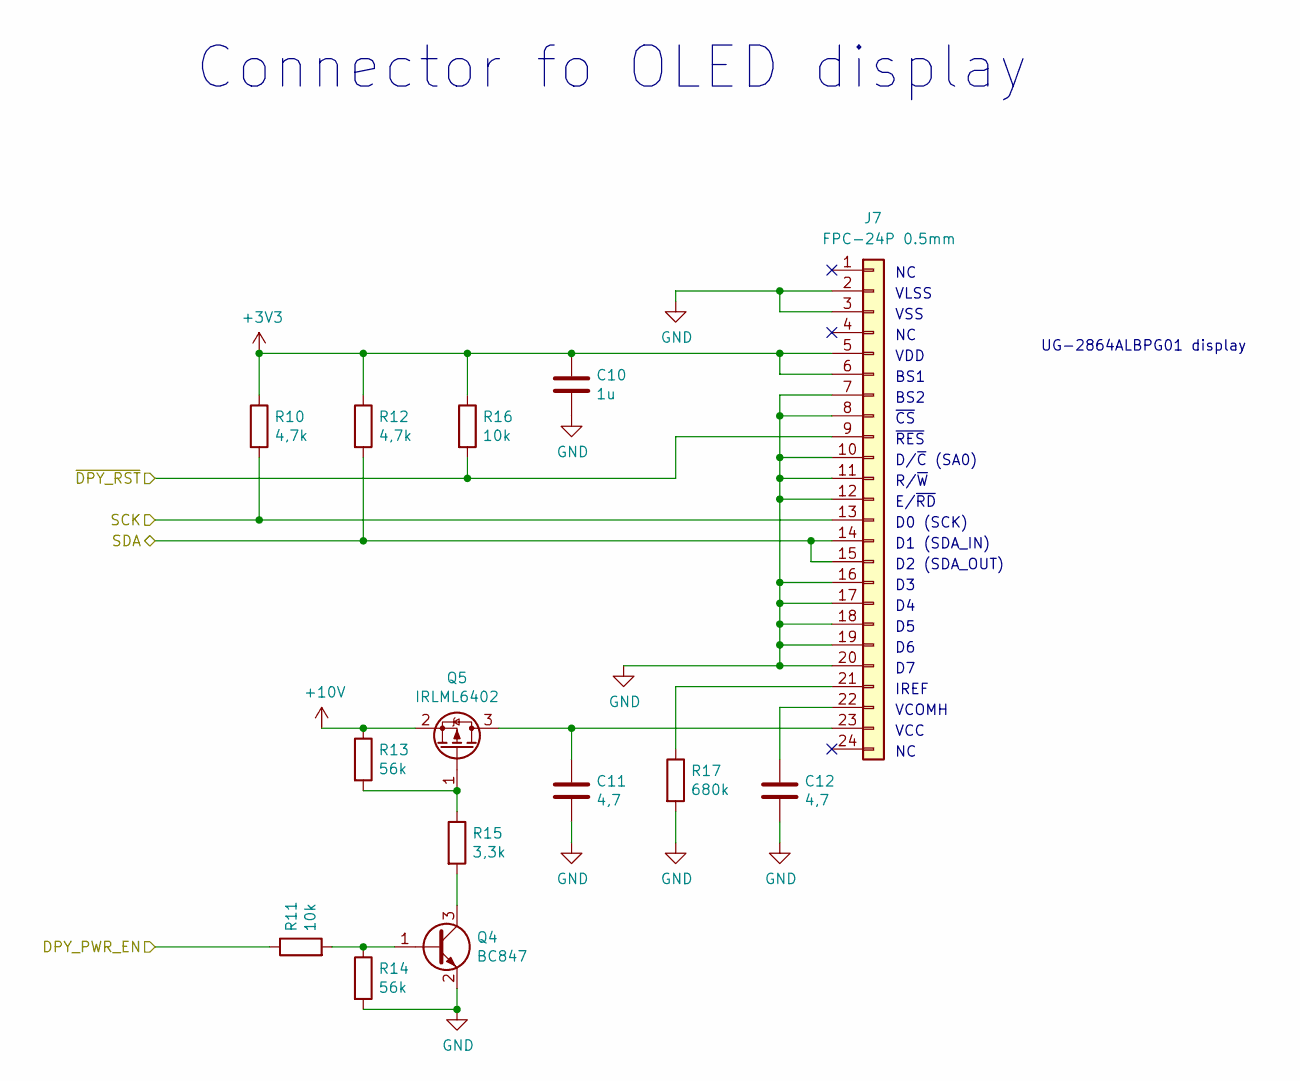
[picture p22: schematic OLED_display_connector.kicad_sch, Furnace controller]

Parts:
C10: 1u; C_0603_1608Metric_Pad1.08x0.95mm_HandSolder
C11, C12: 4,7; C_1206_3216Metric_Pad1.33x1.80mm_HandSolder
J7: FPC-24P 0.5mm; Hirose_FH12-24S-0.5SH_1x24-1MP_P0.50mm_Horizontal
Q4: BC847; SOT-23
Q5: IRLML6402; SOT-23
R10, R12: 4,7k; R_0603_1608Metric_Pad0.98x0.95mm_HandSolder
R11, R16: 10k; R_0603_1608Metric_Pad0.98x0.95mm_HandSolder
R13, R14: 56k; R_0603_1608Metric_Pad0.98x0.95mm_HandSolder
R15: 3,3k; R_0603_1608Metric_Pad0.98x0.95mm_HandSolder
R17: 680k; R_0603_1608Metric_Pad0.98x0.95mm_HandSolder

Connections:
+3V3: C10.1, J7.5, J7.6, R10.1, R12.1, R16.1; also elsewhere on the board
+10V: Q5.2 (S), R13.1; also elsewhere on the board
/MCU/DPY_I2C_SCK: J7.13, R10.2; also elsewhere on the board
/MCU/DPY_I2C_SDA: J7.14, J7.15, R12.2; also elsewhere on the board
/MCU/DPY_PWR_EN: R11.1; also elsewhere on the board
/MCU/~DPY_RST: J7.9, R16.2; also elsewhere on the board
GND: C10.2, C11.2, C12.2, J7.2, J7.3, J7.7, J7.8, J7.10, J7.11, J7.12, J7.16, J7.17, J7.18, J7.19, J7.20, Q4.2 (E), R14.2, R17.2; also elsewhere on the board
unnamed: C11.1, J7.23, Q5.3 (D)
unnamed: C12.1, J7.22
unnamed: J7.21, R17.1
unnamed: Q4.1 (B), R11.2, R14.1
unnamed: Q4.3 (C), R15.2
unnamed: Q5.1 (G), R13.2, R15.1

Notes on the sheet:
BS1
BS2
VLSS
UG-2864ALBPG01 display
R/~{W}
~{RES}
VSS
Connector fo OLED display
VCOMH
E/~{RD}
D/~{C} (SA0)
D1 (SDA_IN)
VCC
IREF
~{CS}
D0 (SCK)
D2 (SDA_OUT)
VDD

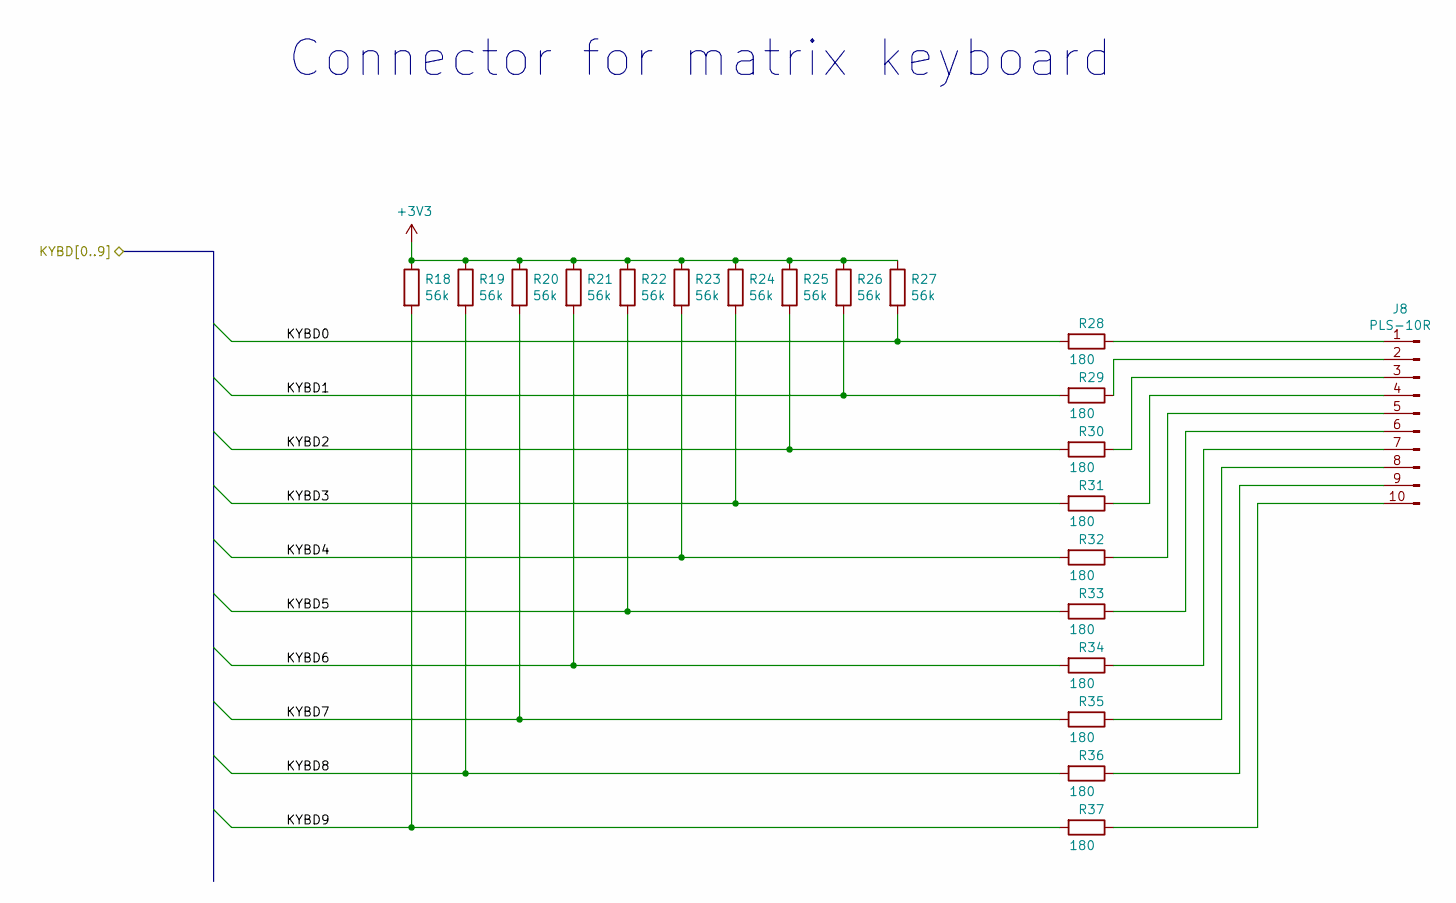
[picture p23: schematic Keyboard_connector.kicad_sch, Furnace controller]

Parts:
J8: PLS-10R; PinHeader_1x10_P2.54mm_Vertical
R18, R19, R20, R21, R22, R23, R24, R25, R26, R27: 56k; R_0603_1608Metric_Pad0.98x0.95mm_HandSolder
R28, R29, R30, R31, R32, R33, R34, R35, R36, R37: 180; R_0603_1608Metric_Pad0.98x0.95mm_HandSolder

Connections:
+3V3: R18.1, R19.1, R20.1, R21.1, R22.1, R23.1, R24.1, R25.1, R26.1, R27.1; also elsewhere on the board
/KEYBOARD_CONNECTOR/KYBD0: R27.2, R28.2; also elsewhere on the board
/KEYBOARD_CONNECTOR/KYBD1: R26.2, R29.2; also elsewhere on the board
/KEYBOARD_CONNECTOR/KYBD2: R25.2, R30.2; also elsewhere on the board
/KEYBOARD_CONNECTOR/KYBD3: R24.2, R31.2; also elsewhere on the board
/KEYBOARD_CONNECTOR/KYBD4: R23.2, R32.2; also elsewhere on the board
/KEYBOARD_CONNECTOR/KYBD5: R22.2, R33.2; also elsewhere on the board
/KEYBOARD_CONNECTOR/KYBD6: R21.2, R34.2; also elsewhere on the board
/KEYBOARD_CONNECTOR/KYBD7: R20.2, R35.2; also elsewhere on the board
/KEYBOARD_CONNECTOR/KYBD8: R19.2, R36.2; also elsewhere on the board
/KEYBOARD_CONNECTOR/KYBD9: R18.2, R37.2; also elsewhere on the board
unnamed: J8.1, R28.1
unnamed: J8.2, R29.1
unnamed: J8.3, R30.1
unnamed: J8.4, R31.1
unnamed: J8.5, R32.1
unnamed: J8.6, R33.1
unnamed: J8.7, R34.1
unnamed: J8.8, R35.1
unnamed: J8.9, R36.1
unnamed: J8.10, R37.1

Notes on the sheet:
Connector for matrix keyboard

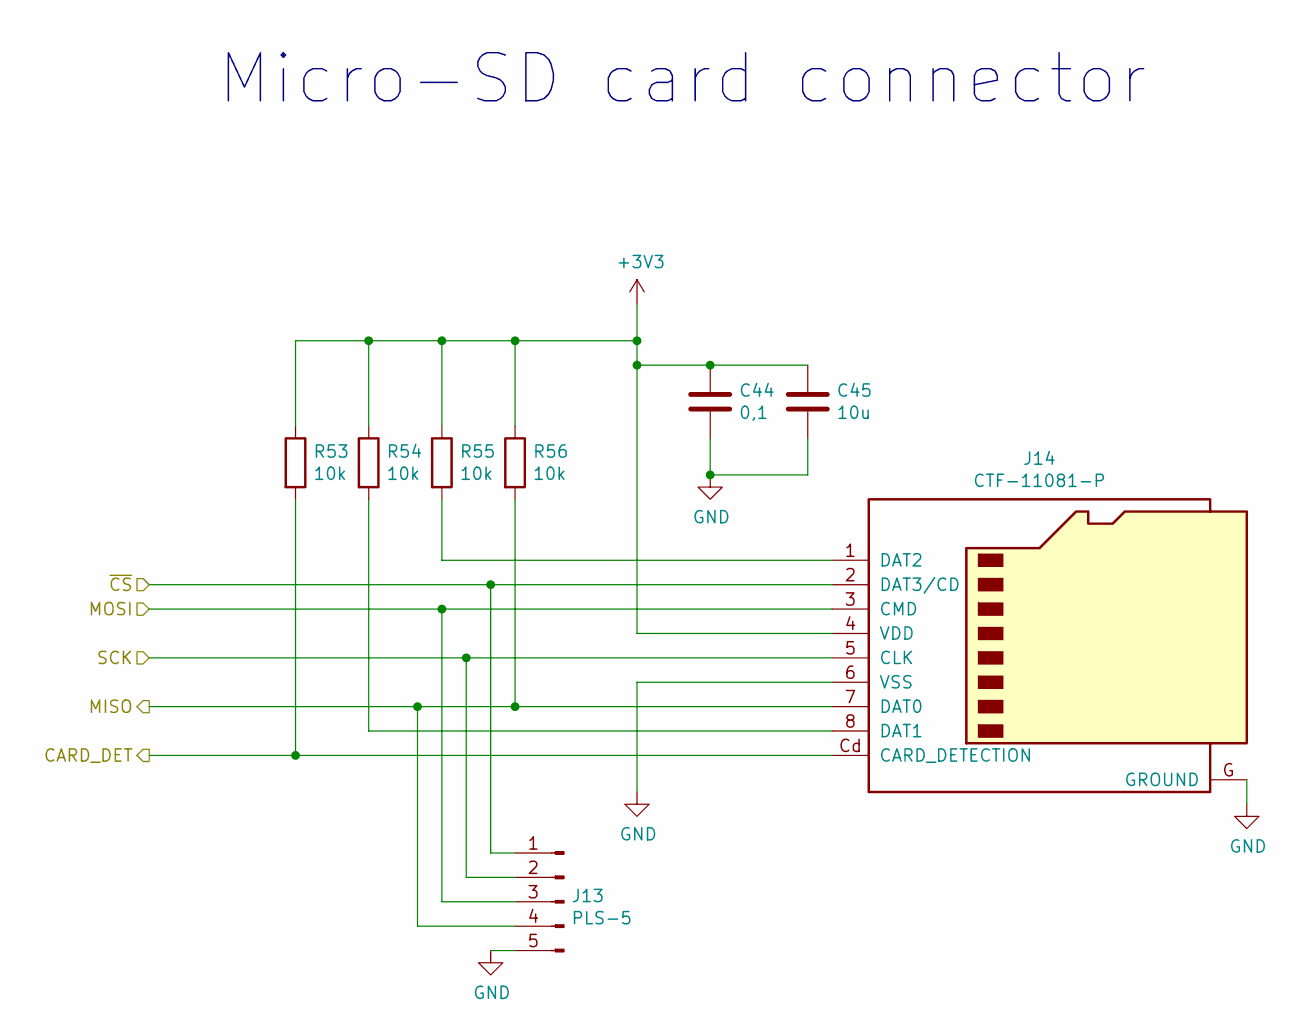
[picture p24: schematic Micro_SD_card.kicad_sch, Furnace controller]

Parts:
C44: 0,1; C_0603_1608Metric_Pad1.08x0.95mm_HandSolder
C45: 10u; C_1206_3216Metric_Pad1.33x1.80mm_HandSolder
J13: PLS-5; PinHeader_1x05_P2.54mm_Vertical
J14: CTF-11081-P
R53, R54, R55, R56: 10k; R_0603_1608Metric_Pad0.98x0.95mm_HandSolder

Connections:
+3V3: C44.1, C45.1, J14.4 (VDD), R53.1, R54.1, R55.1, R56.1; also elsewhere on the board
/MICRO_SD_CARD/CARD_DET: J14.Cd (CARD_DETECTION), R53.2; also elsewhere on the board
/MICRO_SD_CARD/MISO: J13.4, J14.7 (DAT0), R56.2; also elsewhere on the board
/MICRO_SD_CARD/MOSI: J13.3, J14.3 (CMD); also elsewhere on the board
/MICRO_SD_CARD/SCK: J13.2, J14.5 (CLK); also elsewhere on the board
/MICRO_SD_CARD/~CS: J13.1, J14.2 (DAT3/CD); also elsewhere on the board
GND: C44.2, C45.2, J13.5, J14.6 (VSS), J14.G (GROUND); also elsewhere on the board
unnamed: J14.1 (DAT2), R55.2
unnamed: J14.8 (DAT1), R54.2

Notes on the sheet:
Micro-SD card connector

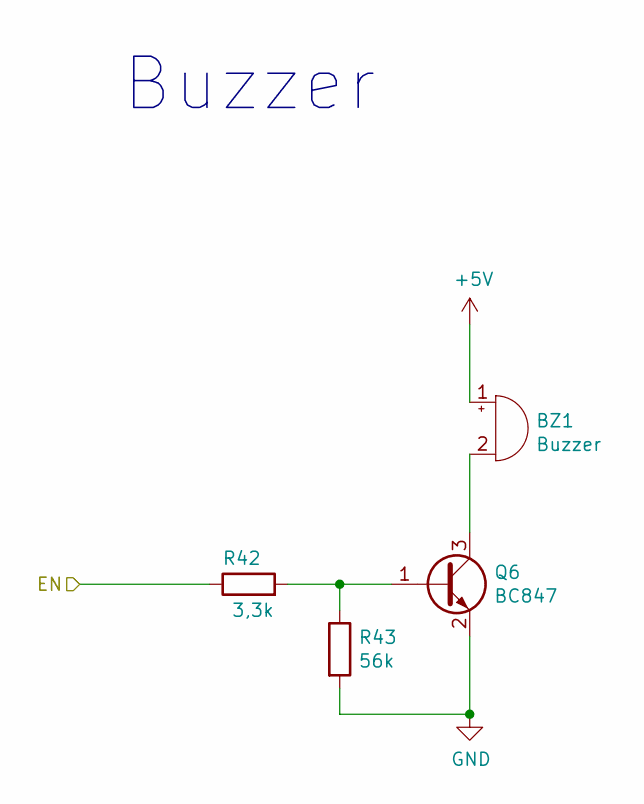
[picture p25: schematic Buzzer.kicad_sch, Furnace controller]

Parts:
BZ1: Buzzer; Buzzer_12x9.5RM7.6
Q6: BC847; SOT-23
R42: 3,3k; R_0603_1608Metric_Pad0.98x0.95mm_HandSolder
R43: 56k; R_0603_1608Metric_Pad0.98x0.95mm_HandSolder

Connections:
+5V: BZ1.1 (+); also elsewhere on the board
/MCU/BZ_EN: R42.1; also elsewhere on the board
GND: Q6.2 (E), R43.2; also elsewhere on the board
unnamed: BZ1.2 (-), Q6.3 (C)
unnamed: Q6.1 (B), R42.2, R43.1

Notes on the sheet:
Buzzer

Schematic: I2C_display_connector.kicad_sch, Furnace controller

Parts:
J10: PLS-4R; PinHeader_1x04_P2.54mm_Horizontal
JP1: Jumper_NC_Dual; PinHeader_1x03_P2.54mm_Vertical
R44, R45: 4,7k; R_0603_1608Metric_Pad0.98x0.95mm_HandSolder

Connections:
+3V3: JP1.3; also elsewhere on the board
+5V: JP1.1; also elsewhere on the board
/MCU/DPY_I2C_SCK: J10.1, R44.2; also elsewhere on the board
/MCU/DPY_I2C_SDA: J10.2, R45.2; also elsewhere on the board
GND: J10.4; also elsewhere on the board
unnamed: J10.3, JP1.2, R44.1, R45.1

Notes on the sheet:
I2C display connector for OLED or LCD display

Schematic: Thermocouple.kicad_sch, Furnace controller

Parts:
C13: 0,01; C_0603_1608Metric_Pad1.08x0.95mm_HandSolder
C14: 0,1; C_0603_1608Metric_Pad1.08x0.95mm_HandSolder
U2: MAX31855EASA; SOIC-8_3.9x4.9mm_P1.27mm

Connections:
/ISOLATED_TEMP_SENSOR/+3V3_ISO: C14.1, U2.4 (V_{CC}); also elsewhere on the board
/ISOLATED_TEMP_SENSOR/ISOLATOR0/OUTB: U2.6 (~CS); also elsewhere on the board
/ISOLATED_TEMP_SENSOR/ISOLATOR2/INC: U2.7 (SO); also elsewhere on the board
/ISOLATED_TEMP_SENSOR/ISOLATOR2/OUTB: U2.5 (SCK); also elsewhere on the board
/TC+0: C13.1, U2.3 (T+); also elsewhere on the board
/TC-0: C13.2, U2.2 (T-); also elsewhere on the board
GND1: C14.2, U2.1 (GND); also elsewhere on the board

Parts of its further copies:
C22, C24, C26, C28: 0,01; C_0603_1608Metric_Pad1.08x0.95mm_HandSolder
C23, C25, C27, C29: 0,1; C_0603_1608Metric_Pad1.08x0.95mm_HandSolder
U5, U6, U7, U8: MAX31855EASA; SOIC-8_3.9x4.9mm_P1.27mm

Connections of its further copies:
/ISOLATED_TEMP_SENSOR/+3V3_ISO: C23.1, C25.1, C27.1, C29.1, U5.4 (V_{CC}), U6.4 (V_{CC}), U7.4 (V_{CC}), U8.4 (V_{CC}); also elsewhere on the board
/ISOLATED_TEMP_SENSOR/ISOLATOR0/OUTA: U5.6 (~CS); also elsewhere on the board
/ISOLATED_TEMP_SENSOR/ISOLATOR1/OUTA: U7.6 (~CS); also elsewhere on the board
/ISOLATED_TEMP_SENSOR/ISOLATOR1/OUTB: U6.6 (~CS); also elsewhere on the board
/ISOLATED_TEMP_SENSOR/ISOLATOR2/INC: U5.7 (SO), U6.7 (SO), U7.7 (SO), U8.7 (SO); also elsewhere on the board
/ISOLATED_TEMP_SENSOR/ISOLATOR2/OUTA: U8.6 (~CS); also elsewhere on the board
/ISOLATED_TEMP_SENSOR/ISOLATOR2/OUTB: U5.5 (SCK), U6.5 (SCK), U7.5 (SCK), U8.5 (SCK); also elsewhere on the board
/TC+1: C22.1, U5.3 (T+); also elsewhere on the board
/TC+2: C24.1, U6.3 (T+); also elsewhere on the board
/TC+3: C26.1, U7.3 (T+); also elsewhere on the board
/TC+4: C28.1, U8.3 (T+); also elsewhere on the board
/TC-1: C22.2, U5.2 (T-); also elsewhere on the board
/TC-2: C24.2, U6.2 (T-); also elsewhere on the board
/TC-3: C26.2, U7.2 (T-); also elsewhere on the board
/TC-4: C28.2, U8.2 (T-); also elsewhere on the board
GND1: C23.2, C25.2, C27.2, C29.2, U5.1 (GND), U6.1 (GND), U7.1 (GND), U8.1 (GND); also elsewhere on the board

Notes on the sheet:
Thermocouple sensor

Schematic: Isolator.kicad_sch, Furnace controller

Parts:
C15, C16: 0,1; C_0603_1608Metric_Pad1.08x0.95mm_HandSolder
U3: ADuM1301; SOIC-16W_7.5x10.3mm_P1.27mm

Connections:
+3V3: C16.1, U3.1 (VDD1), U3.7 (VE1); also elsewhere on the board
/ISOLATED_TEMP_SENSOR/+3V3_ISO: C15.1, U3.10 (VE2), U3.16 (VDD2); also elsewhere on the board
/ISOLATED_TEMP_SENSOR/ISOLATOR0/OUTA: U3.14 (VOA); also elsewhere on the board
/ISOLATED_TEMP_SENSOR/ISOLATOR0/OUTB: U3.13 (VOB); also elsewhere on the board
/ISOLATED_TEMP_SENSOR/ISOLATOR0/OUTC: U3.5 (VOC)
/ISOLATED_TEMP_SENSOR/~CS0: U3.3 (VIA); also elsewhere on the board
/ISOLATED_TEMP_SENSOR/~CS1: U3.4 (VIB); also elsewhere on the board
GND: C16.2, U3.2 (GND1), U3.8 (GND1); also elsewhere on the board
GND1: C15.2, U3.9 (GND2), U3.12 (VIC), U3.15 (GND2); also elsewhere on the board

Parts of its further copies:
C30, C31, C32, C33: 0,1; C_0603_1608Metric_Pad1.08x0.95mm_HandSolder
U9, U10: ADuM1301; SOIC-16W_7.5x10.3mm_P1.27mm

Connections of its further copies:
+3V3: C31.1, C33.1, U9.1 (VDD1), U9.7 (VE1), U10.1 (VDD1), U10.7 (VE1); also elsewhere on the board
/ISOLATED_TEMP_SENSOR/+3V3_ISO: C30.1, C32.1, U9.10 (VE2), U9.16 (VDD2), U10.10 (VE2), U10.16 (VDD2); also elsewhere on the board
/ISOLATED_TEMP_SENSOR/ISOLATOR1/OUTA: U9.14 (VOA); also elsewhere on the board
/ISOLATED_TEMP_SENSOR/ISOLATOR1/OUTB: U9.13 (VOB); also elsewhere on the board
/ISOLATED_TEMP_SENSOR/ISOLATOR1/OUTC: U9.5 (VOC)
/ISOLATED_TEMP_SENSOR/ISOLATOR2/INC: U10.12 (VIC); also elsewhere on the board
/ISOLATED_TEMP_SENSOR/ISOLATOR2/OUTA: U10.14 (VOA); also elsewhere on the board
/ISOLATED_TEMP_SENSOR/ISOLATOR2/OUTB: U10.13 (VOB); also elsewhere on the board
/ISOLATED_TEMP_SENSOR/MISO: U10.5 (VOC); also elsewhere on the board
/ISOLATED_TEMP_SENSOR/SCK: U10.4 (VIB); also elsewhere on the board
/ISOLATED_TEMP_SENSOR/~CS2: U9.3 (VIA); also elsewhere on the board
/ISOLATED_TEMP_SENSOR/~CS3: U9.4 (VIB); also elsewhere on the board
/ISOLATED_TEMP_SENSOR/~CS4: U10.3 (VIA); also elsewhere on the board
GND: C31.2, C33.2, U9.2 (GND1), U9.8 (GND1), U10.2 (GND1), U10.8 (GND1); also elsewhere on the board
GND1: C30.2, C32.2, U9.9 (GND2), U9.12 (VIC), U9.15 (GND2), U10.9 (GND2), U10.15 (GND2); also elsewhere on the board

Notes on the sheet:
Isolator for thermocouple

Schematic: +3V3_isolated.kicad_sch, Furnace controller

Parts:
C17: 4,7; C_1206_3216Metric_Pad1.33x1.80mm_HandSolder
C18, C20: 10u; C_1206_3216Metric_Pad1.33x1.80mm_HandSolder
C19: 0,1; C_0603_1608Metric_Pad1.08x0.95mm_HandSolder
C21: 1u; C_0603_1608Metric_Pad1.08x0.95mm_HandSolder
FB1: Ferrite_Bead; L_0805_2012Metric_Pad1.05x1.20mm_HandSolder
PS1: B0505S-1WR2; B_S-1WR3; PARTREV 2018.12.05-B/2
R38, R39: 680; R_0603_1608Metric_Pad0.98x0.95mm_HandSolder
R40: 240 1%; R_0603_1608Metric_Pad0.98x0.95mm_HandSolder
R41: 390 1%; R_0603_1608Metric_Pad0.98x0.95mm_HandSolder
TP5, TP6: TestPoint; TP
U4: LM317L_SO8; SOIC-8_3.9x4.9mm_P1.27mm

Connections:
+5V: C17.1, PS1.2 (VIN); also elsewhere on the board
/ISOLATED_TEMP_SENSOR/+3V3_ISO: C21.1, R40.1, TP5.1, U4.2 (VO), U4.3 (VO), U4.6 (VO), U4.7 (VO); also elsewhere on the board
GND: C17.2, PS1.1 (GND); also elsewhere on the board
GND1: C18.2, C19.2, C20.2, C21.2, PS1.3 (0V), R38.2, R39.2, R41.2, TP6.1; also elsewhere on the board
unnamed: C18.1, FB1.2, PS1.4 (+VO)
unnamed: C19.1, FB1.1, R38.1, R39.1, U4.1 (VI)
unnamed: C20.1, R40.2, R41.1, U4.4 (ADJ)

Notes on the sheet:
Isolated +3V3 power source

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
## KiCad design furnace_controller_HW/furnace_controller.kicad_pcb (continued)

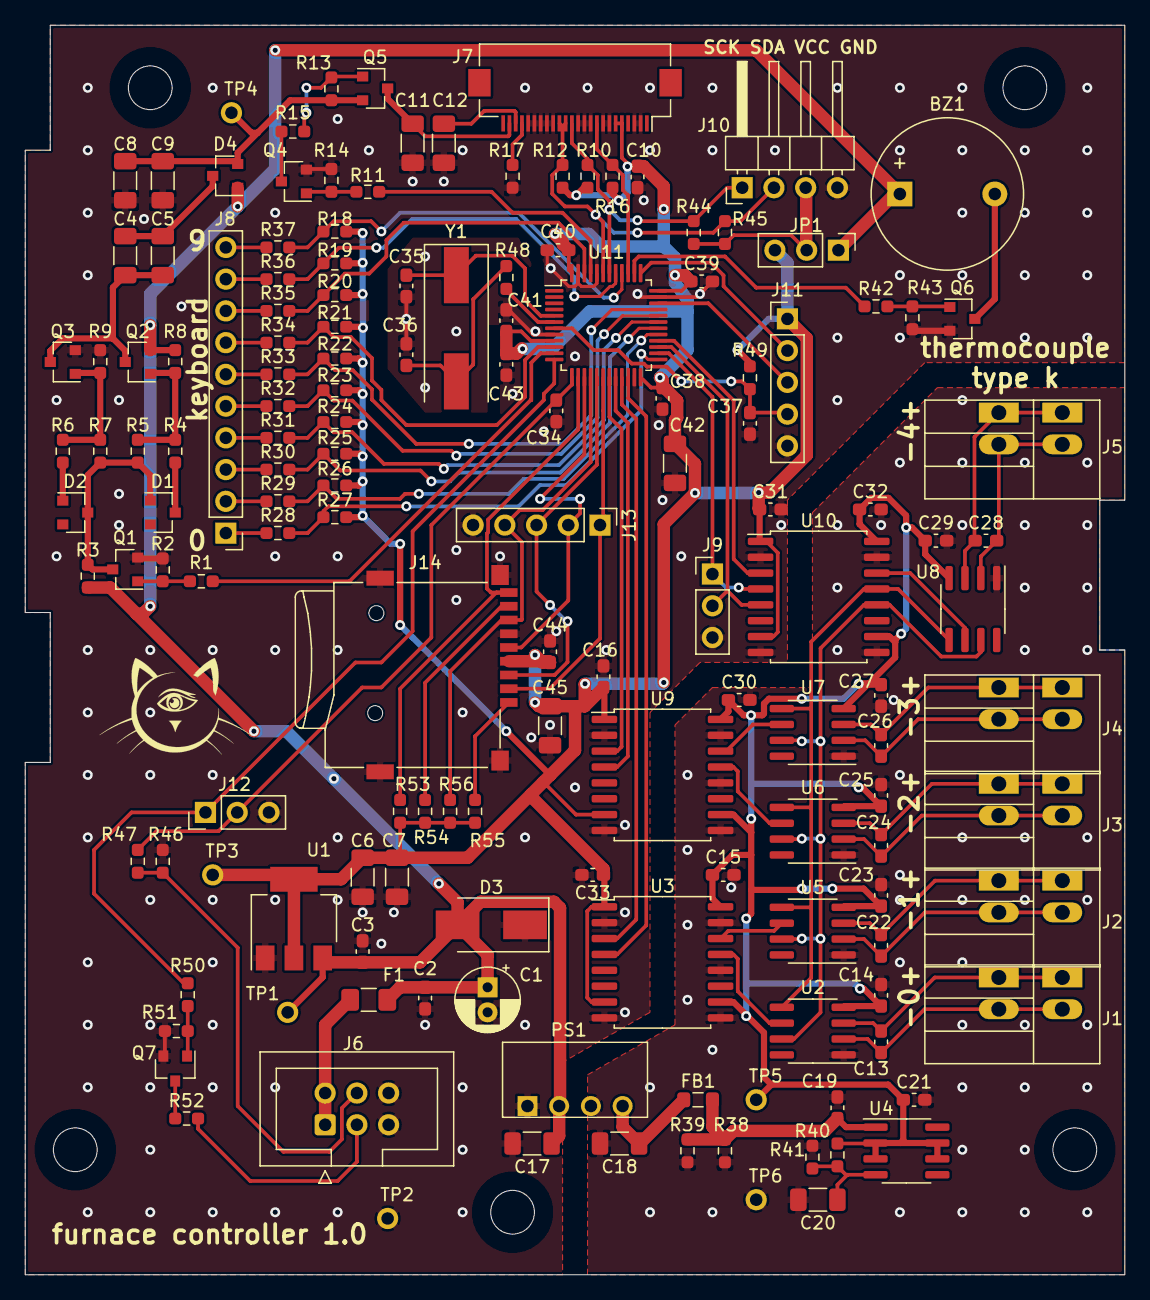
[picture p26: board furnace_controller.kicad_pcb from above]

Board: 2 copper layers, 88.0 x 100.0 mm, 155 parts (0 on the bottom side), 96 nets.

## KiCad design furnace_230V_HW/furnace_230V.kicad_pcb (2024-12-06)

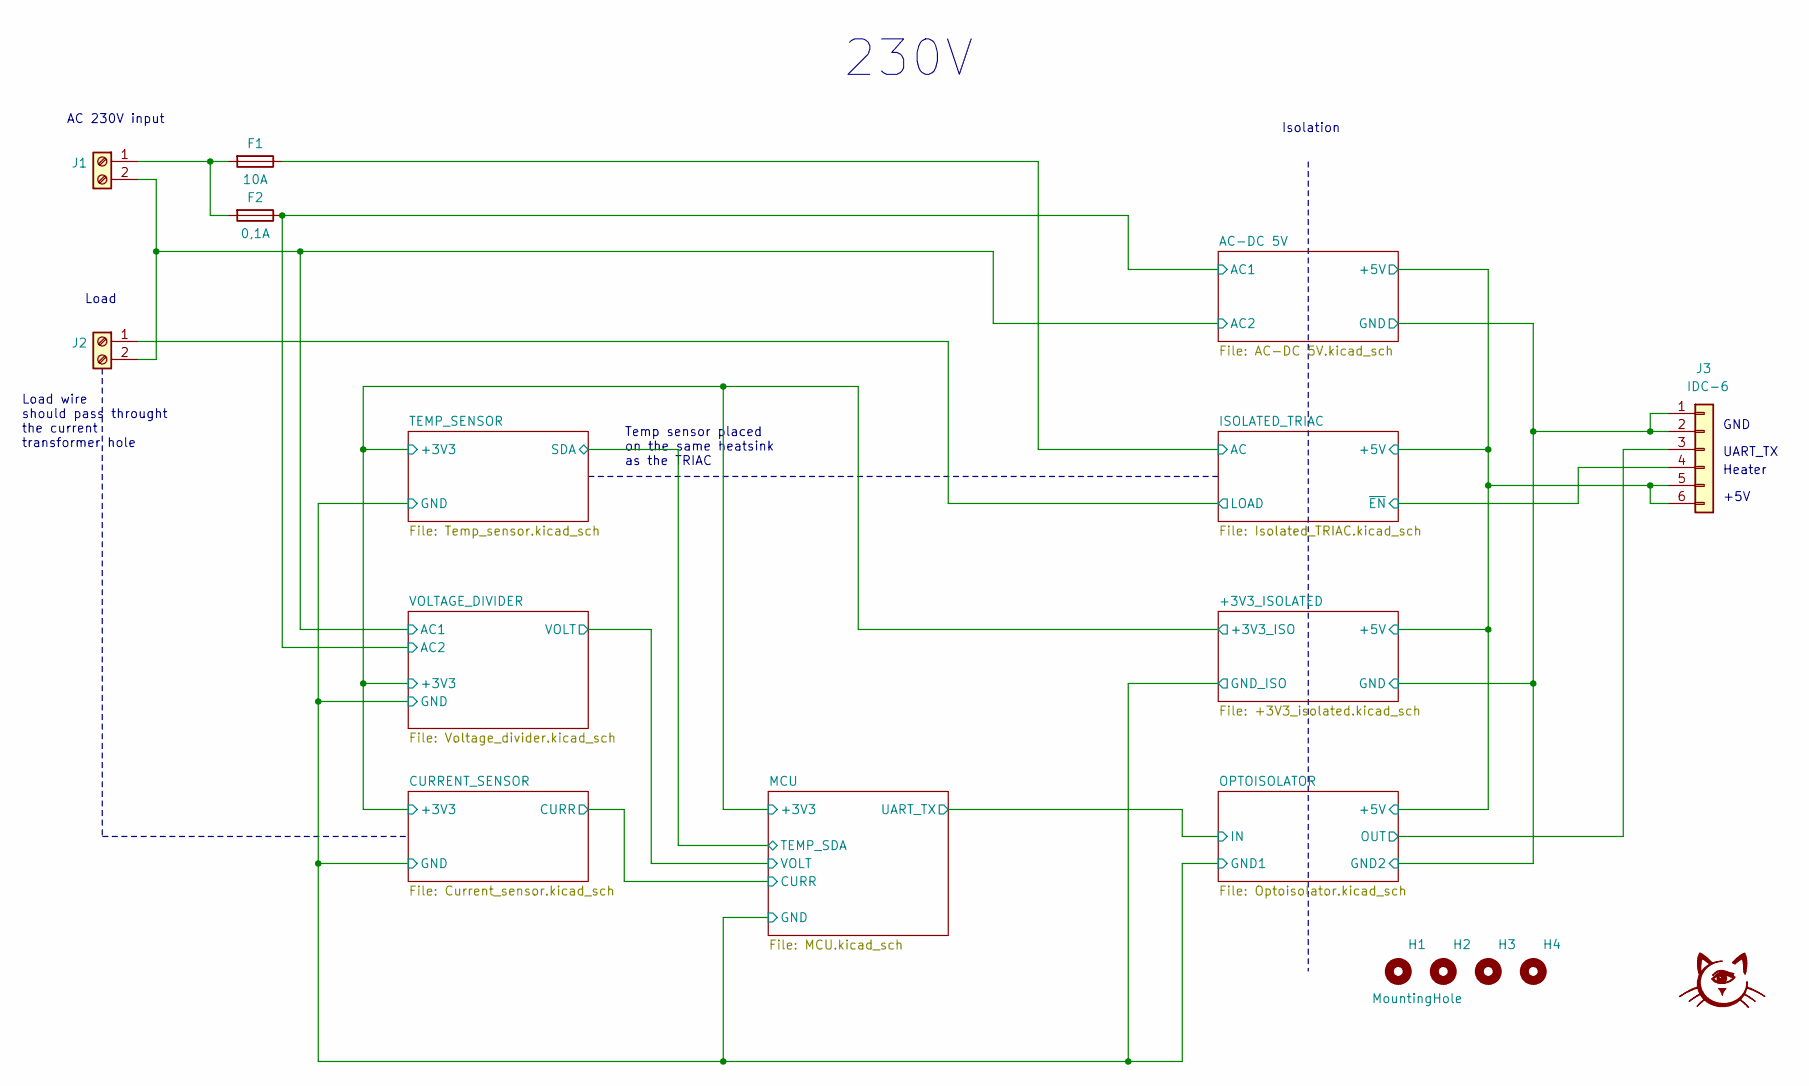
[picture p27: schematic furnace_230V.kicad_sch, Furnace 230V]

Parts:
F1: 10A; Fuseholder_Cylinder-5x20mm_Stelvio-Kontek_PTF78_Horizontal_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
F2: 0,1A; Fuseholder_Cylinder-5x20mm_Stelvio-Kontek_PTF78_Horizontal_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
G1: LOGO; stamp
H1, H2, H3, H4: MountingHole; hole_D3.5mm
J1, J2: KF7.62-2P
J3: IDC-6; IDC-Header_2x03_P2.54mm_Vertical

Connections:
/+3V3_ISOLATED/+5V: J3.5, J3.6; also elsewhere on the board
/+3V3_ISOLATED/GND: J3.1, J3.2; also elsewhere on the board
/AC-DC 5V/AC1: F2.1; also elsewhere on the board
/ISOLATED_TRIAC/AC: F1.1; also elsewhere on the board
/ISOLATED_TRIAC/LOAD: J2.1; also elsewhere on the board
/ISOLATED_TRIAC/~EN: J3.4; also elsewhere on the board
/OPTOISOLATOR/OUT: J3.3; also elsewhere on the board
/VOLTAGE_DIVIDER/AC1: J1.2, J2.2; also elsewhere on the board
unnamed: F1.2, F2.2, J1.1

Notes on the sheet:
GND
Isolation
230V
Load wire should pass throught the current transformer hole
AC 230V input
UART_TX
Load
Heater
Temp sensor placed on the same heatsink as the TRIAC
+5V

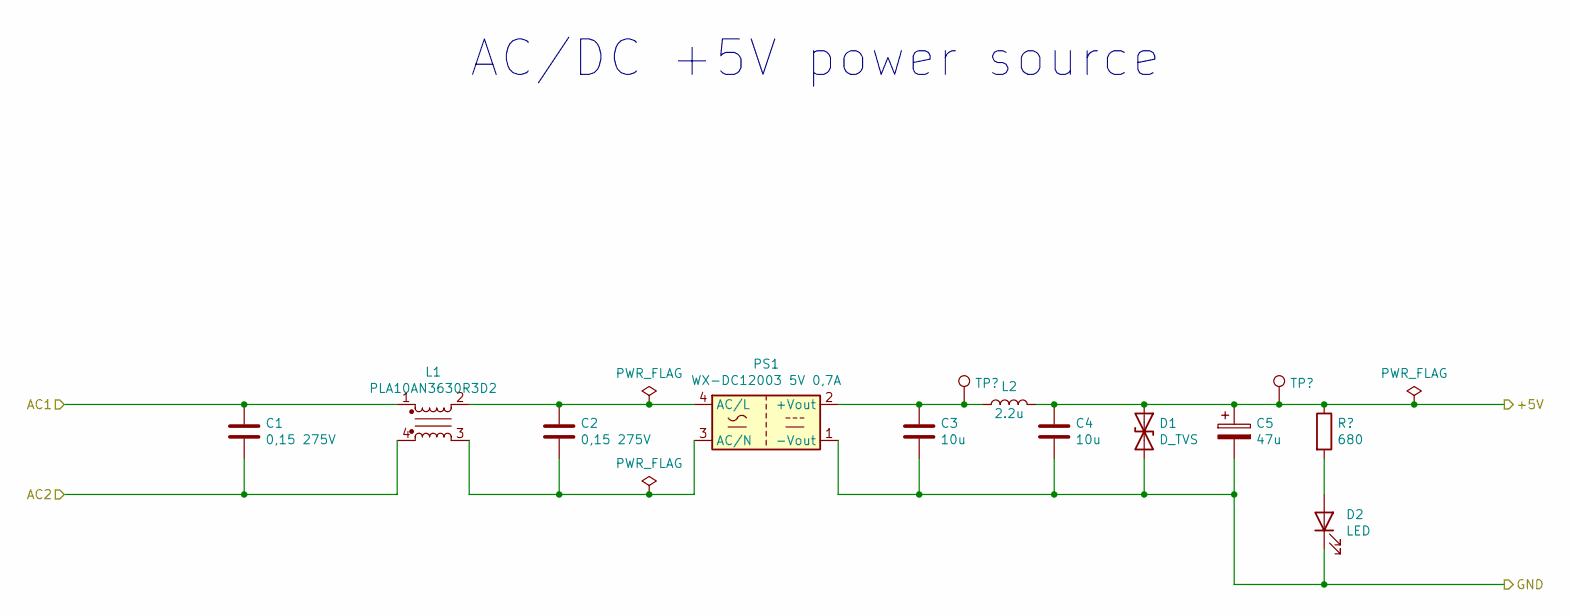
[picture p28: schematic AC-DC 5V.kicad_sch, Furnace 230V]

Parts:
C1, C2: 0,15 275V; C_Rect_L18.0mm_W7.0mm_P15.00mm_FKS3_FKP3
C3, C4: 10u; C_1206_3216Metric_Pad1.42x1.75mm_HandSolder
C5: 47u; CP_Radial_D5.0mm_P2.00mm
D1: D_TVS; D_SMB_Handsoldering
D2: LED; LED_1206_3216Metric_ReverseMount_Hole1.8x2.4mm
L1: PLA10AN3630R3D2; L_CommonMode_PLA10
L2: 2.2u; L_Axial_L7.0mm_D3.3mm_P10.16mm_Horizontal_Fastron_MICC
PS1: WX-DC12003 5V 0,7A; WX-DC12003
R1: 680; R_0603_1608Metric_Pad1.05x0.95mm_HandSolder
TP1, TP2: TestPoint; TP

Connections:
/+3V3_ISOLATED/+5V: C4.1, C5.1, D1.1 (A1), L2.2, R1.1, TP2.1; also elsewhere on the board
/+3V3_ISOLATED/GND: C3.2, C4.2, C5.2, D1.2 (A2), D2.1 (K), PS1.1 (-Vout); also elsewhere on the board
/AC-DC 5V/AC1: C1.1, L1.1; also elsewhere on the board
/VOLTAGE_DIVIDER/AC1: C1.2, L1.4; also elsewhere on the board
unnamed: C2.1, L1.2, PS1.4 (AC/L)
unnamed: C2.2, L1.3, PS1.3 (AC/N)
unnamed: C3.1, L2.1, PS1.2 (+Vout), TP1.1
unnamed: D2.2 (A), R1.2

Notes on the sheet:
AC/DC +5V power source

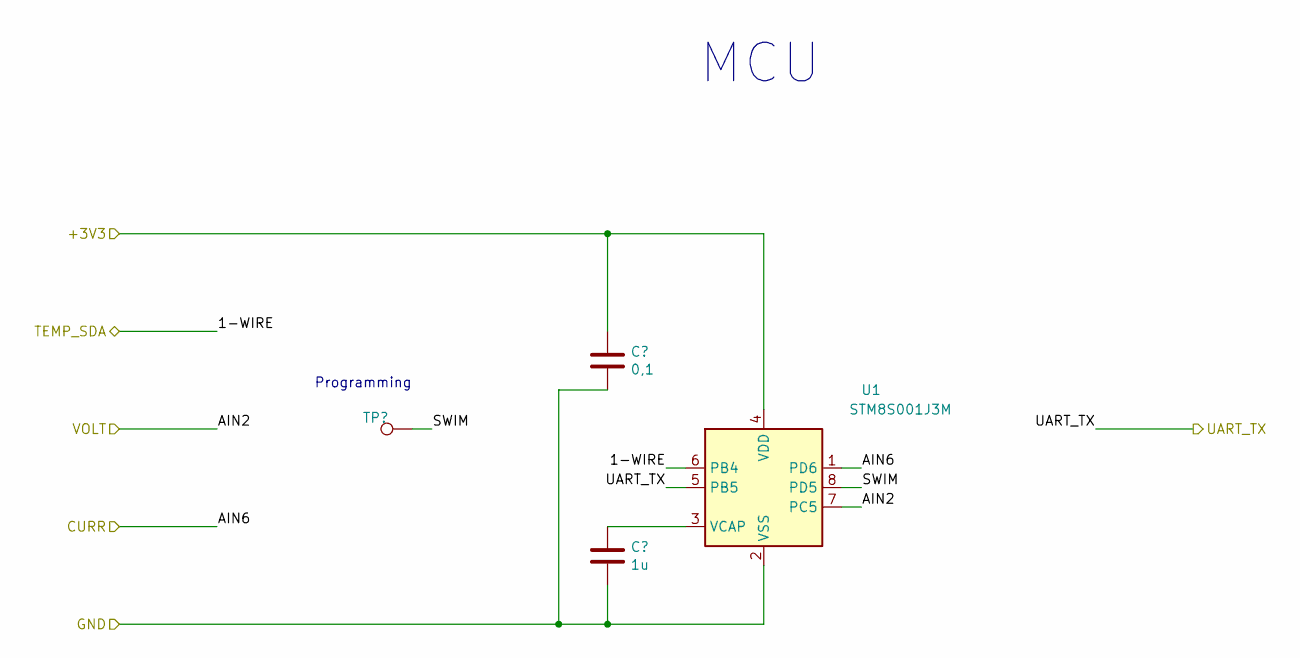
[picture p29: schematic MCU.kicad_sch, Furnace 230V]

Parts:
C6: 0,1; C_0603_1608Metric_Pad1.05x0.95mm_HandSolder
C7: 1u; C_0603_1608Metric_Pad1.05x0.95mm_HandSolder
TP3: TestPoint; TP
U1: STM8S001J3M; SOIC-8_3.9x4.9mm_P1.27mm

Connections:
/CURRENT_SENSOR/+3V3: C6.1, U1.4 (VDD); also elsewhere on the board
/CURRENT_SENSOR/CURR: U1.1 (PD6); also elsewhere on the board
/CURRENT_SENSOR/GND: C6.2, C7.2, U1.2 (VSS); also elsewhere on the board
/MCU/SWIM: TP3.1, U1.8 (PD5)
/MCU/VOLT: U1.7 (PC5); also elsewhere on the board
/OPTOISOLATOR/IN: U1.5 (PB5); also elsewhere on the board
/TEMP_SENSOR/SDA: U1.6 (PB4); also elsewhere on the board
unnamed: C7.1, U1.3 (VCAP)

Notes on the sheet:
MCU
Programming


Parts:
C8: 4,7; C_1206_3216Metric_Pad1.42x1.75mm_HandSolder
C9, C11: 10u; C_1206_3216Metric_Pad1.42x1.75mm_HandSolder
C10: 0,1; C_0603_1608Metric_Pad1.05x0.95mm_HandSolder
C12: 1u; C_0603_1608Metric_Pad1.05x0.95mm_HandSolder
PS2: B0505S-1WR2; B_S-1WR3; PARTREV 2018.12.05-B/2
R2, R3: 680; R_0603_1608Metric_Pad1.05x0.95mm_HandSolder
R4: 240 1%; R_0603_1608Metric_Pad1.05x0.95mm_HandSolder
R5: 390 1%; R_0603_1608Metric_Pad1.05x0.95mm_HandSolder
TP4, TP5: TestPoint; TP
U2: LM317L_SO8; SOIC-8_3.9x4.9mm_P1.27mm

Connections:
/+3V3_ISOLATED/+5V: C8.1, PS2.2 (VIN); also elsewhere on the board
/+3V3_ISOLATED/GND: C8.2, PS2.1 (GND); also elsewhere on the board
/CURRENT_SENSOR/+3V3: C12.1, R4.1, TP4.1, U2.2 (VO), U2.3 (VO), U2.6 (VO), U2.7 (VO); also elsewhere on the board
/CURRENT_SENSOR/GND: C9.2, C10.2, C11.2, C12.2, PS2.3 (0V), R2.2, R3.2, R5.2, TP5.1; also elsewhere on the board
unnamed: C9.1, C10.1, PS2.4 (+VO), R2.1, R3.1, U2.1 (VI)
unnamed: C11.1, R4.2, R5.1, U2.4 (ADJ)

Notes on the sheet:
Isolated +3V3 power source


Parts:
D3: LED; LED_1206_3216Metric_ReverseMount_Hole1.8x2.4mm
HS1: HS 304-50; HS_304-50
Q1: BTA16-600B; TRIAC
R6: 150; R_0603_1608Metric_Pad1.05x0.95mm_HandSolder
R7: 470 0,5W; R_Axial_DIN0309_L9.0mm_D3.2mm_P12.70mm_Horizontal
U3: MOC3052M; DIP-6_W7.62mm_LongPads

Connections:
/+3V3_ISOLATED/+5V: R6.2; also elsewhere on the board
/ISOLATED_TRIAC/AC: Q1.2 (A2), R7.1; also elsewhere on the board
/ISOLATED_TRIAC/LOAD: Q1.1 (A1); also elsewhere on the board
/ISOLATED_TRIAC/~EN: U3.2; also elsewhere on the board
unnamed: D3.1 (K), U3.1
unnamed: D3.2 (A), R6.1
unnamed: Q1.3 (G), U3.4
unnamed: R7.2, U3.6

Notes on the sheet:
Isolated TRIAC control circuit


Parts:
C13: 0,1; C_0603_1608Metric_Pad1.05x0.95mm_HandSolder
R8: 4,7k; R_0603_1608Metric_Pad1.05x0.95mm_HandSolder
TP6: TestPoint; TP
U4: DS18B20; TO-92_Inline

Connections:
/CURRENT_SENSOR/+3V3: C13.1, R8.1, U4.3 (VDD); also elsewhere on the board
/CURRENT_SENSOR/GND: C13.2, U4.1 (GND); also elsewhere on the board
/TEMP_SENSOR/SDA: R8.2, TP6.1, U4.2 (DQ); also elsewhere on the board

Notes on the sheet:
1-wire temperature sensor


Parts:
C17, C19: 100; C_0603_1608Metric_Pad1.05x0.95mm_HandSolder
C18: 10u; C_0603_1608Metric_Pad1.05x0.95mm_HandSolder
D7: BAT54S; SOT-23
D8: D_TVS; D_SMB_Handsoldering
R16: 160 1%; R_0603_1608Metric_Pad1.05x0.95mm_HandSolder
R17, R18: 10k 1%; R_0603_1608Metric_Pad1.05x0.95mm_HandSolder
R19: 100; R_0603_1608Metric_Pad1.05x0.95mm_HandSolder
R20: 1k; R_0603_1608Metric_Pad1.05x0.95mm_HandSolder
T1: ZMCT103C
TP11, TP12, TP13: TestPoint; TP

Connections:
/CURRENT_SENSOR/+3V3: C18.1, D7.2, R17.1; also elsewhere on the board
/CURRENT_SENSOR/CURR: C19.1, R20.1, TP13.1; also elsewhere on the board
/CURRENT_SENSOR/GND: C18.2, C19.2, D7.1, D8.1 (A1), R18.2; also elsewhere on the board
unnamed: C17.1, R16.1, R19.2, T1.2, TP11.1
unnamed: C17.2, R16.2, R17.2, R18.1, T1.1, TP12.1
unnamed: D7.3, D8.2 (A2), R19.1, R20.2

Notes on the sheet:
Load current measurement circuit


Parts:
C14, C16: 100; C_0603_1608Metric_Pad1.05x0.95mm_HandSolder
C15: 10u; C_0603_1608Metric_Pad1.05x0.95mm_HandSolder
D4: ES1J; D_SMA_Handsoldering
D5: BAT54S; SOT-23
D6: D_TVS; D_SMB_Handsoldering
R9, R11: 180k 0,25W 1%; R_Axial_DIN0207_L6.3mm_D2.5mm_P10.16mm_Horizontal
R10: 3,3k 1%; R_0603_1608Metric_Pad1.05x0.95mm_HandSolder
R12: 100; R_0603_1608Metric_Pad1.05x0.95mm_HandSolder
R13: 1k; R_0603_1608Metric_Pad1.05x0.95mm_HandSolder
TP7, TP8, TP9: TestPoint; TP

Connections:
/AC-DC 5V/AC1: R11.2; also elsewhere on the board
/CURRENT_SENSOR/+3V3: C15.1, D5.2; also elsewhere on the board
/CURRENT_SENSOR/GND: C14.2, C15.2, C16.2, D5.1, D6.1 (A1), R10.2, R11.1, TP8.1; also elsewhere on the board
/MCU/VOLT: C16.1, R13.1, TP9.1; also elsewhere on the board
/VOLTAGE_DIVIDER/AC1: D4.2 (A); also elsewhere on the board
unnamed: C14.1, R9.2, R10.1, R12.2, TP7.1
unnamed: D4.1 (K), R9.1
unnamed: D5.3, D6.2 (A2), R12.1, R13.2

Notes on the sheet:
Input 230V voltage measurement circuit

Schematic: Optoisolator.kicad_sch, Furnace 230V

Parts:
R14: 680; R_0603_1608Metric_Pad1.05x0.95mm_HandSolder
R15: 3,3k; R_0603_1608Metric_Pad1.05x0.95mm_HandSolder
TP10: TestPoint; TP
U5: H11L1; DIP-6_W7.62mm_LongPads

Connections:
/+3V3_ISOLATED/+5V: R15.1, U5.6; also elsewhere on the board
/+3V3_ISOLATED/GND: U5.5; also elsewhere on the board
/CURRENT_SENSOR/GND: U5.2; also elsewhere on the board
/OPTOISOLATOR/IN: R14.2, TP10.1; also elsewhere on the board
/OPTOISOLATOR/OUT: R15.2, U5.4; also elsewhere on the board
unnamed: R14.1, U5.1

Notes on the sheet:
UART isolator



Board: 2 copper layers, 85.0 x 90.0 mm, 82 parts (43 on the bottom side), 34 nets.

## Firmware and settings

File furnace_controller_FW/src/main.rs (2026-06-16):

#![deny(unsafe_code)]
#![no_main]
#![no_std]


use crc::{Crc, CRC_8_MAXIM_DOW};
use embedded_graphics::{
    pixelcolor::BinaryColor,
    prelude::*,
};
use embedded_hal::delay::DelayNs;
use max31855::{Max31855, Unit};
use micromath::F32Ext;
use rtt_target::rtt_init_log;
use rtic_monotonics::systick::prelude::*;
use u8g2_fonts::{fonts, FontRenderer, types::*};
use rtic_sync::{channel::*, make_channel};

use furnace_controller::utils::{calculate_rms, parse_rx_data};

systick_monotonic!(Mono, 1000);

use furnace_controller::bsp::{
    Board,
    Board230Rx,
    Board230Error,
    DigitalOutput,
    hal,
    Key,
    Keyboard,
    KeySet,
    OledDisplay,
    IndependentWatchdog,
    TempSpi,
    TEMP_NUM,
    RX_DATA_LEN,
    RxData,
};



#[rtic::app(device = hal::pac, peripherals = true, dispatchers = [EXTI0, EXTI1])]
mod app {

    use super::*;


    #[shared]
    struct Shared {}

    #[local]
    struct Local {
        oled: OledDisplay,
        heater_control: &'static mut DigitalOutput,
        buzzer: DigitalOutput,
        keyboard: Keyboard,
        watchdog: IndependentWatchdog,
        temp_select: [DigitalOutput; 5],
        temp_spi: TempSpi,
        board230_rx: Board230Rx,
        rx_byte_sender: Sender<'static, Result<u8, Board230Error>, RX_DATA_LEN>
    }

    #[init]
    fn init(cx: init::Context) -> (Shared, Local) {

        rtt_init_log!();

        let board = Board::new(cx.device);
        let mut oled = board.oled;
        let heater_control = board.heater_control;
        let mut buzzer = board.buzzer;
        let keyboard = board.keyboard;
        let watchdog = board.watchdog;
        let temp_select = board.temp_select;
        let temp_spi = board.temp_spi;
        let mut board230_rx = board.board230_rx;

        Mono::start(cx.core.SYST, board.rcc.clocks.sysclk().to_Hz());
        
        oled.init().expect("Display initialization error");

        Mono::delay_ms(&mut Mono, 1000);
        buzzer.set_high();
        Mono::delay_ms(&mut Mono, 1000);
        buzzer.set_low();
        log::info!("Initialization finished");

        let (keys_sender, keys_receiver) = make_channel!(KeySet, 1);
        let (temp_sender, temp_receiver) = make_channel!([Option<i16>; 5], 1);
        let (rx_byte_sender, rx_byte_receiver) = make_channel!(Result<u8, Board230Error>, RX_DATA_LEN);
        let (rx_data_sender, rx_data_receiver) = make_channel!(Result<RxData, Board230Error>, 1);
        let (smile_sender, smile_receiver) = make_channel!(&str, 1);

        board230_rx.listen();

        control::spawn(keys_receiver, temp_receiver, rx_data_receiver, smile_receiver).ok();
        keyboard::spawn(keys_sender).ok();
        temp::spawn(temp_sender).ok();
        decode::spawn(rx_byte_receiver, rx_data_sender).ok();
        watchdog::spawn().ok();
        smile::spawn(smile_sender).ok();


        (
            Shared {
               
            },
            Local {
               heater_control,
               oled,
               buzzer,
               keyboard,
               watchdog,
               temp_select,
               temp_spi,
               board230_rx,
               rx_byte_sender,
            },
        )
    }


    #[task(local = [oled, buzzer, heater_control], priority = 1)]
    async fn control(cx: control::Context,
        mut keys_receiver: Receiver<'static, KeySet, 1>,
        mut temp_receiver: Receiver<'static, [Option<i16>; TEMP_NUM], 1>,
        mut rx_data_receiver: Receiver<'static, Result<RxData, Board230Error>, 1>,
        mut smile_receiver: Receiver<'static, &'static str, 1>,
    ) {

        let control::LocalResources
            {oled, buzzer, heater_control, ..} = cx.local;

        let font = FontRenderer::new::<fonts::u8g2_font_synchronizer_nbp_tf>();

        let mut update_disp = false;
        // Thermocouples temperatures
        let mut temperatures = heapless::String::<40>::new();
        // Data from the 230V board
        let mut rx_data = heapless::String::<40>::new();
        let mut smile = "";

        loop {
            Mono::delay(10.millis()).await;

            if let Ok(keys) = keys_receiver.try_recv() {

                buzzer.set_high();
                Mono::delay(10.millis()).await;
                buzzer.set_low();

                if keys.contains(&Key::Asterisk) {
                    heater_control.toggle();
                }
            }
            
            if let Ok(temp) = temp_receiver.try_recv() {

                temperatures.clear();
                let mut buf = [0u8; 10];
                for i in 0..TEMP_NUM {

                    let message = match temp[i] {
                        Some(number) => {

                            let str: &str = format_no_std::show(
                            &mut buf,
                            format_args!("{}°C\n", 
                            number)).expect("Formatting error");
                            str
                        }
                        None => "--\n"
                    };
                    temperatures.push_str(message).expect("String push error");
                }
                update_disp = true;
            }

            if let Ok(data) = rx_data_receiver.try_recv() {

                rx_data.clear();
                match data {
                    Ok(data) => {
                        let mut buf = [0u8; 40];
                        let str: &str = format_no_std::show(
                            &mut buf,
                            format_args!("U: {}V\nI: {}.{}A\nP: {}W\nT: {}°C\n",
                                data.voltage,
                                data.current / 10,
                                data.current % 10,
                                data.voltage * data.current / 10,
                                data.triac_temp 
                            )).expect("Formatting error");
                        rx_data.push_str(str).expect("String push error");
                    }
                    Err(Board230Error::UartError) => {
                        rx_data.push_str("UartError").expect("String push error");
                    }
                    Err(Board230Error::CrcError) => {
                        rx_data.push_str("CrcError").expect("String push error");
                    }
                    Err(Board230Error::ParseError) => {
                        rx_data.push_str("ParseError").expect("String push error");
                    }
                    Err(Board230Error::NoTempValue) => {
                        rx_data.push_str("NoTempValue").expect("String push error");
                    }
                }
                
                update_disp = true;
            }

            if let Ok(new_smile) = smile_receiver.try_recv() {
                smile = new_smile;
            }

            if update_disp {
                oled.clear();

                let offset = Point::new(40, 0);
                font.render_aligned(
                    temperatures.as_str(),
                    oled.bounding_box().center() + offset,
                    VerticalPosition::Center,
                    HorizontalAlignment::Center,
                    FontColor::Transparent(BinaryColor::On),
                    oled,
                )
                .ok();

                let offset = Point::new(-60, 0);
                font.render_aligned(
                    rx_data.as_str(),
                    oled.bounding_box().center() + offset,
                    VerticalPosition::Center,
                    HorizontalAlignment::Left,
                    FontColor::Transparent(BinaryColor::On),
                    oled,
                )
                .ok();

                let offset = Point::new(5, 0);
                font.render_aligned(
                    smile,
                    oled.bounding_box().center() + offset,
                    VerticalPosition::Center,
                    HorizontalAlignment::Center,
                    FontColor::Transparent(BinaryColor::On),
                    oled,
                )
                .ok();

                oled.flush().expect("OLED flush error");
                update_disp = false;
            }
        }
    }


    // Read 230V board data: voltage, current, triac temperature
    // Higher priority to avoid overrun error
    #[task(binds = USART2, local = [board230_rx, rx_byte_sender], priority = 2)]
    fn board230_uart(cx: board230_uart::Context) {

        let board230_uart::LocalResources
            {board230_rx, rx_byte_sender, ..} = cx.local;

        let byte = board230_rx.read().map_err(|_err|{
            Board230Error::UartError
        });
        rx_byte_sender.try_send(byte).ok();
    }


    // Collect and parse 230V board data
    #[task(priority = 1)]
    async fn decode(
        _cx: decode::Context,
        mut rx_byte_receiver: Receiver<'static, Result<u8, Board230Error>, RX_DATA_LEN>,
        mut rx_data_sender: Sender<'static, Result<RxData, Board230Error>, 1>) {

        let mut buf = heapless::Deque::<u8, RX_DATA_LEN>::new();
        const CRC: Crc<u8> = Crc::<u8>::new(&CRC_8_MAXIM_DOW);

        loop {
            match rx_byte_receiver.recv().await.expect("Receiver error") {
                Ok(byte) => {
                    buf.push_back(byte).ok();
                }
                Err(err) => {
                    rx_data_sender.send(Err(err)).await.expect("Sender error");
                }
            }
            // Full package received?
            if buf.is_full() {
                if *buf.front().expect("Buffer error") != b'U' {
                    // Wrong package start -> continue collecting data
                    buf.pop_front().expect("Buffer error");
                    continue;
                }

                buf.make_contiguous();
                let input = buf.as_slices().0;

                if CRC.checksum(&input) != 0 {
                    rx_data_sender.send(Err(Board230Error::CrcError)).await.expect("Sender error");
                    continue;
                }

                let processed = parse_rx_data(&input).map(calculate_rms);
                rx_data_sender.send(processed).await.expect("Sender error");
            }
        }
    }


    // Read keyboard
    #[task(local = [keyboard], priority = 1)]
    async fn keyboard(cx: keyboard::Context, mut keys_sender: Sender<'static, KeySet, 1>) {

        let keyboard::LocalResources
            {keyboard, ..} = cx.local;

        loop {
            Mono::delay(2.millis()).await;
            keyboard.proceed();
            let state = keyboard.get_pressed();

            if !state.is_empty() {
                keys_sender.send(state).await.ok();
            }
        }
    }


    // Read thermocouples data
    #[task(local = [temp_select, temp_spi], priority = 1)]
    async fn temp(cx: temp::Context, mut temp_sender: Sender<'static, [Option<i16>; TEMP_NUM], 1>) {

        let temp::LocalResources
            {temp_select, temp_spi, ..} = cx.local;

        let mut data = [None::<i16>; TEMP_NUM];

        loop {
            Mono::delay(1000.millis()).await;

            for (chip_select, data) in temp_select.iter_mut().zip(data.iter_mut()) {
                *data = match temp_spi.read_all(chip_select, Unit::Celsius) {
                    Ok(result) => {
                        let temperature = result.thermocouple.round() as i16;
                        log::info!("Thermocouple read: {}°C", temperature);
                        Some(temperature)
                    },
                    Err(err) => {
                        log::error!("Thermocouple read error: {:?}", err);
                        None
                    }
                };
                Mono::delay(10.millis()).await; 
            }
            temp_sender.send(data).await.expect("Sender error");
        }
    }


    #[task(priority = 1)]
    async fn smile(_cx: smile::Context, mut smile_sender: Sender<'static, &'static str, 1>) {

        loop {   
            let smile = "^_^";
            smile_sender.send(smile).await.expect("Sender error");
            Mono::delay(2000.millis()).await;

            let smile = "^_~";
            smile_sender.send(smile).await.expect("Sender error");
            Mono::delay(500.millis()).await;

            log::info!("Blink!");
        }
    }


    #[task(local = [watchdog], priority = 1)]
    async fn watchdog(cx: watchdog::Context) {

        let watchdog::LocalResources
            {watchdog, ..} = cx.local;

        loop {
            
            watchdog.feed();
            Mono::delay(2000.millis()).await;
        }
    }


    #[idle]
    fn idle(_: idle::Context) -> ! {

        loop {
            continue;
        }
    }
}

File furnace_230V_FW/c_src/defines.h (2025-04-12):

#include <stdint.h>

// Imitation of WASM internal functions
#define DIV_U(x, y)         (x) / (y)
#define REM_U(x, y)         (x) % (y)
#define I32_DIV_S(x, y)     (x) / (y)

#define UNREACHABLE         while (1) {}


#define MAX_RAM_ADDR        0x03FF


typedef uint8_t u8;
typedef int8_t s8;
typedef uint16_t u16;
typedef int16_t s16;
typedef uint32_t u32;
typedef int32_t s32;
typedef uint64_t u64;

// Functions to solve little/big endianness conflict:
// little-endian for WASM and big-endian for STM8
inline uint16_t reverse_byte_order16(uint16_t value) {
    typedef union
    {
        uint16_t word;
        uint8_t bytes[2];
    } dword;

    dword res, val;
    val.word = value;
    res.bytes[0] = val.bytes[1];
    res.bytes[1] = val.bytes[0];

    return res.word;
}

inline uint32_t reverse_byte_order32(uint32_t value) {
    typedef union
    {
        uint32_t dword;
        uint8_t bytes[4];
    } dword;

    dword res, val;
    val.dword = value;
    res.bytes[0] = val.bytes[3];
    res.bytes[1] = val.bytes[2];
    res.bytes[2] = val.bytes[1];
    res.bytes[3] = val.bytes[0];

    return res.dword;
}

inline uint64_t reverse_byte_order64(uint64_t value) {
    typedef union
    {
        uint64_t qword;
        uint8_t bytes[8];
    } qword;

    qword res, val;
    val.qword = value;
    res.bytes[0] = val.bytes[7];
    res.bytes[1] = val.bytes[6];
    res.bytes[2] = val.bytes[5];
    res.bytes[3] = val.bytes[4];
    res.bytes[4] = val.bytes[3];
    res.bytes[5] = val.bytes[2];
    res.bytes[6] = val.bytes[1];
    res.bytes[7] = val.bytes[0];

    return res.qword;
}

// Functions to store data in memory / load from memory.
// If address is within RAM -> byte order to be reversed as data in RAM
// are stored as little-endian (WASM).
// But if address is outside RAM -> no reversal needed as peripheral register are big-endian (STM8).

inline void i32_store8(uint64_t addr, uint8_t value){
    *(volatile uint8_t *)(addr) = value;
}

inline void i32_store16(uint64_t addr, uint16_t value) {
    if (addr < MAX_RAM_ADDR) {
        value = reverse_byte_order16(value);
    }
    *(volatile uint16_t *)(addr) = value;
}

inline void i32_store(uint64_t addr, int32_t value) {
    if (addr < MAX_RAM_ADDR) {
        value = reverse_byte_order32(value);
    }
    *(volatile int32_t *)(addr) = value;
}

inline void i64_store(uint64_t addr, uint64_t value) {
    if (addr < MAX_RAM_ADDR) {
        value = reverse_byte_order64(value);
    }
    *(volatile uint64_t *)(addr) = value;
}

inline uint32_t i32_load8_u(uint64_t addr) {
    uint32_t value = *(volatile uint8_t *)(addr);
    return value;
}

inline int32_t i32_load8_s(uint64_t addr) {
    uint32_t value = *(volatile int8_t *)(addr);
    return value;
}

inline int32_t i32_load16_u(uint64_t addr) {
    uint32_t value = *(volatile uint16_t *)(addr);
    if (addr < MAX_RAM_ADDR) {
        value = reverse_byte_order16(value);
    }
    return value;
}

inline int32_t i32_load16_s(uint64_t addr) {
    uint32_t value = *(volatile int16_t *)(addr);
    if (addr < MAX_RAM_ADDR) {
        value = reverse_byte_order16(value);
    }
    return value;
}

inline int32_t i32_load(uint64_t addr) {
    uint32_t value = *(volatile int32_t *)(addr);
    if (addr < MAX_RAM_ADDR) {
        value = reverse_byte_order32(value);
    }
    return value;
}

inline int64_t i64_load(uint64_t addr) {
    int64_t value = *(volatile int64_t *)(addr);
    if (addr < MAX_RAM_ADDR) {
        value = reverse_byte_order64(value);
    }
    return value;
}

// To work with variables via indirect addressing.
// Ensure variables are created in RAM.
// Lenght can be increased, but be aware of stack overflow!
#define MEMORY_LENGTH 50
uint8_t memory[MEMORY_LENGTH];

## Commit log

2024-12-05 Change directories structure
    [+3V3_isolated.sch, AC-DC 5V.sch, ADUM1301ARWZ-RL.step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]
2024-12-06 Resave in KiCad 8
    [+3V3_isolated.kicad_sch, +3V3_isolated.sch, AC-DC 5V.kicad_sch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]
2025-03-27 Add charge pump simulation
    [charge_pump_simulation.kicad_sch]
2025-03-29 Tune FETs switchng times and frequency
    [charge_pump_simulation.kicad_sch]
2025-04-12 Add ADC values proceeding
2025-04-12 Add sensor ds18b20
2025-04-12 Add board support package
2025-04-15 Change directory structure
    [charge_pump_simulation.kicad_sch]
2025-04-15 Add digital filter simulation
2025-04-15 Add digital filter
2025-04-16 Add temperature sensor error handling
    [bsp.rs, lib.rs]
2026-01-04 Add buzzer and keyboard
    [bsp.rs, lib.rs, main.rs]
2026-01-08 Fix the 230V board UART input
    [+3V3_isolated.kicad_sch, Buzzer.kicad_sch, I2C_display_connector.kicad_sch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]
2026-01-08 Resave in Kicad 9
    [furnace_controller.kicad_pcb]
2026-01-08 Tune resistor values for the proper charge pump MOSFETs deadtime
    [Power_3V3_10V.kicad_sch]
2026-01-09 Add reading data from the 230V board
2026-03-08 Add controller board enclosure
    [const.scad, enclosure.scad, recess.scad]
2026-03-08 Finalize enclosure
    [const.scad, enclosure.scad, recess.scad]
2026-06-18 Add thermocouple data pin pull-up
